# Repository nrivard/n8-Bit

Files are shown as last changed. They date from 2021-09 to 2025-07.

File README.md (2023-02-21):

# n8 Bit Microcomputer

The n8 Bit Microcomputer is a homebrew breadboard computer built around a WDC65C02 8-bit CPU.
If you are looking for the software that runs on this computer, check out [LmaOS](https://github.com/nrivard/lmaos).

## History

The n8 Bit was originally a breadboard computer based on the [Ben Eater series of 6502 videos](https://www.youtube.com/playlist?list=PLowKtXNTBypFbtuVMUVXNR0z1mu7dp7eH) but with some added capabilities including ACIA support, GAL-based address decoding logic, and a power chip for more reliable reset and power-on.
Since then, PCBs have been printed and development around the computer is based on these.

nate bit microcomputer on a breadboard

## Physical Design

Large PCBs are expensive and I am not a rich person.
For this reason, the main goal of the physical design of this computer and the expansion cards is to fit on the $5 boards at the cheap PCB houses.
This gives a maximum area of 100mm x 100mm, which this board attempts to utilize to the utmost.

## Main Board

The v2 main board is built around a WDC65C02 CPU operating at 3.6864Mhz and is meant to be as minimally viable as possible. It consists of:

* 3 memory sockets (AT28C256/CY62256 footprint) for a configurable mix of RAM and/or ROM
* SC28L92 DUART for serial communication and built-in timer(s)
* CH340 USB-to-serial chip
* Micro USB port for power (D+/D- are connected to the CH340)
* GAL22V10 for flexible address decoding
* Crystal oscillator can for stable clock generation
* 74HC21 for multi-device IRQ and handling (supports older open-collector devices with jumpers on built-in pull-up resistors)
* DS1813 for reset and power-on circuitry
* 3 n8 Bus ports for I/O

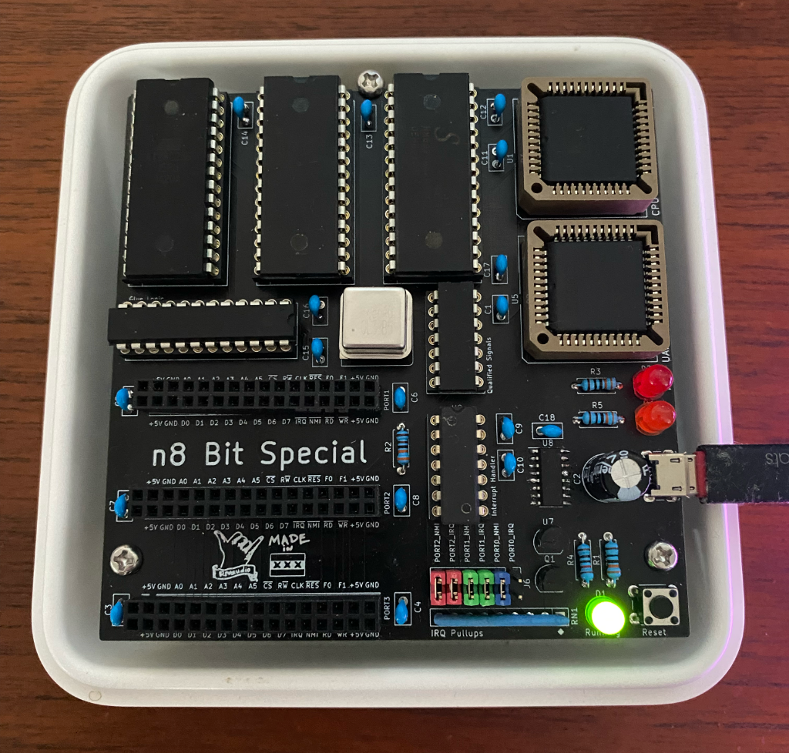
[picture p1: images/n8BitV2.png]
nate bit microcomputer, version 1


### Changes from v1

* Moved from 4 n8 Bus ports down to 3. This was mainly for space reasons and one of the previous ports was always dedicated to serial communication and a VIA for a timer. By moving both of these onto the board, we can give some more breathing room to 3 expansion ports instead
* Moved to half-size oscillator can and increased speed to 3.6864 MHz. The DUART runs at this frequency so I made this the main clock as well.
* Moved to PLCC-44 packaging for CPU and DUART. This not only looks cooler but it has a smaller footprint and allowed me more room to lay out additional components.
* Added transistor stage to the "running" light so it shows when it's actually running, not just when there is power to the board. Pressing and holding RESET will drive this LED off while RESET is low.
* Added qualified (ANDed with CLK) read and write signals to the board and to the n8 Bus ports, replacing D+/D-.
* Ran CLK into the GAL in case I want to use its signal to qualify future signals.
* Moved from 2 layer to 4 layer board. So many signals! Also, this is auto-routed, I don't care, I'm not a purist in this (one) sense

nate bit microcomputer, version 1

## Address space

By default, the n8 Bit is intended to have the following memory hardware:

* 1 Atmel AT28C256 in the ROM1 socket
* 2 Cypress CY62256NL in the RAM1 and RAM2 sockets

### Default Memory Layout

If you are using the default hardware and the included GAL code, it has the following memory layout:

| Device | Address Range |
|---|---|
| Zero Page | `$0000...$00FF` |
| Stack | `$0100...$01FF` |
| RAM | `$0200...$BEFF` |
| Port 0 | `$BF00...$BF3F` |
| Port 1 | `$BF40...$BF7F` |
| Port 2 | `$BF80...$BFBF` |
| DUART | `$BFC0...$BFFF` |
| ROM | `$C000...$FFFF` |

This configuration has 16K of ROM, 48k (less one page) of RAM, and 1 page of memory (`$BF00...$BFFF`) dedicated to 3 I/O ports and the DUART, each of which has 64 addressable memory locations.

### Customizing the Address Space

Because address decoding is entirely GAL based, you have a lot of room to customize the address space.
The GAL itself has physical connections to each port and to each memory socket for CS signals. How you utilize these (or even _if_ you utilize them) is entirely up to you.
If you wanted a simpler computer (like the Ben Eater computer) you may opt to leave one memory socket open and only use a single RAM and a single ROM chip.
If you go this route, you will have to update your own GAL code to match your hardware configuration.

## n8 Bus

The biggest advancement with the n8 Bit when it moved from breadboards to custom PCBs is the introduction of the n8 Bus spec.

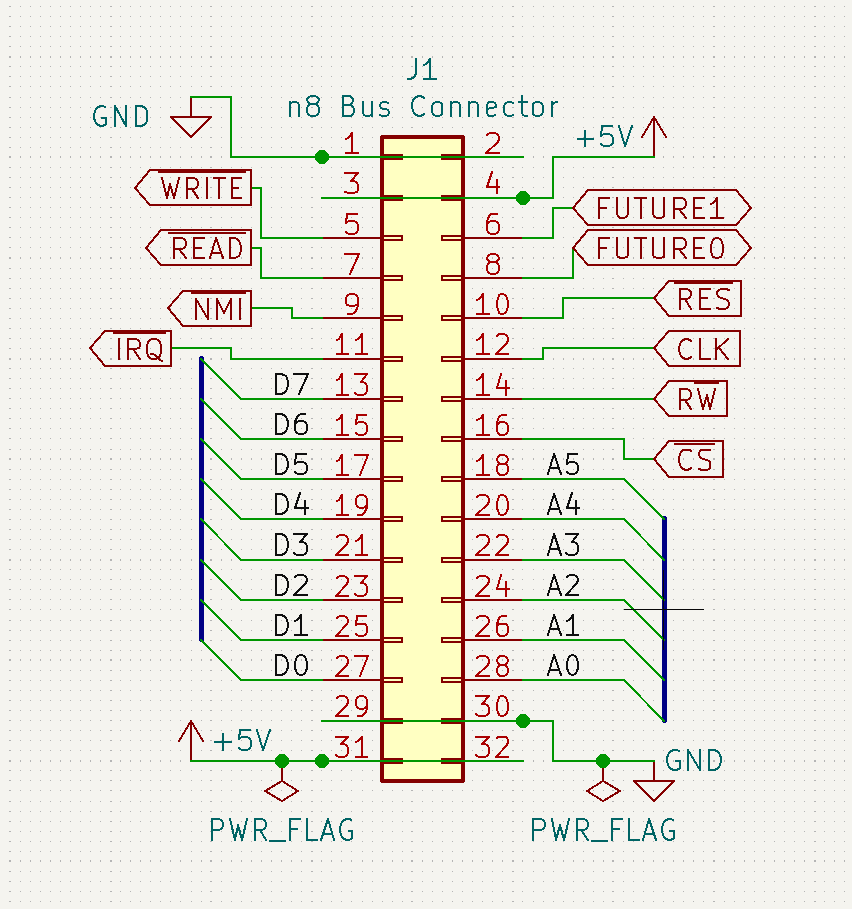
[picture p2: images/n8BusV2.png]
nate bus schematic, version 1


The spec mandates that the following signals will be available on a standard 2x16 board-to-board female header:

**Bidirectional signals:**

* all 8 bits of the data bus

**Read-only signals:**

* bottom 6 bits of the address bus
* per-port dedicated <SPAN STYLE="text-decoration:overline">CS</SPAN> signal
* CPU's R/<SPAN STYLE="text-decoration:overline">W</SPAN> signal
* <SPAN STYLE="text-decoration:overline">READ</SPAN> signal qualified with high part of the CLK
* <SPAN STYLE="text-decoration:overline">WRITE</SPAN> signal qualified with high part of the CLK
* CLK
* <SPAN STYLE="text-decoration:overline">RESET</SPAN>

**Write-only signals:**

* per-port <SPAN STYLE="text-decoration:overline">NMI</SPAN>
* per-port <SPAN STYLE="text-decoration:overline">IRQ</SPAN>

**Expansion signals:**

The n8 Bus spec includes 2 lines (`FUTURE0` and `FUTURE1`) that don't currently have a purpose.
These are hooked up to 2 I/O pins of the GAL and are intended for you to customize them.
For example, if you have a VDP that outputs a colorburst clock that you want to use to drive a sound adapter, you can route that signal through one of these pins.

**Power Rails:**

The n8 Bus spec provides power rails (+5V and ground) on both the top and bottom of the header for shorter, more convenient power routing on your expansions cards.

## I/O Expansion Cards

The main board for this computer is intentionally minimal.
This means that all of your I/O functionality beyond a DUART (VIA, display, sound, etc.) has to come in the form of an expansion card that sits in a n8 Bus port.

### Reference Cards

Two highly utilized devices that many hobbyists want to include on a homebrew computer are a UART (this is unnecessary now on the v2 board but is kept for reference purposes) and a GPIO device.
In this repo, 2 such reference designs are included:

* a UART card based on the Rockwell 65C51, called Kids Serial
* a GPIO (and other functions) card based on the WDC65C22S, called Viaduct

### Custom Cards

If you want to create your own cards, it's best to copy one of the existing reference designs first.
This is because they will already have:

* the n8 Bus port with proper pin directionality _for the card_ in the schematic
* a standardized PCB footprint
* some device footprints (like the 2x16 right-angle male pin header) set

This will ensure you have consistent and correct card designs from the start.

Kids Serial, a UART card, version 1

## Interrupts

<SPAN STYLE="text-decoration:overline">NMI</SPAN> and <SPAN STYLE="text-decoration:overline">IRQ</SPAN> are supported for all 3 n8 Bus ports.
This board uses a WDC65C02 which uses a totem-pole design (the NMOS 6502 used an open-drain design) and so the board also includes optional jumpers for pull-up resistors. In general:

* if your device is open-drain (older 6551s) or your device does not support interrupts at all, you will need to **_add_** jumpers across the interrupt lines for that port
* if your device is totem-pole (WDC65C22S), you will want to **_remove_** the jumpers as the pull-up resistor will slow down signal change

See [this article from Garth Wilson](http://wilsonminesco.com/6502primer/IRQconx.html) for more information.

## Known Bugs

There are no known hardware bugs with the v2 board.
If you find one (or more) please raise an issue.

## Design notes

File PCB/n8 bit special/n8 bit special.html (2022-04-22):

# /Users/nrivard/Code/github/n8-Bit/PCB/n8 bit special/n8 bit special.sch

2022 February 22, Tuesday 14:28:18

Eeschema (5.1.12-1-10_14)

Component Count:48

Ref | Qnty | Value | Part | Footprint | Description | Vendor
C1, C3, C4, C5, C6, C7, C8, C11, C12, C13, C14, C15, C16 | 13 | 100nf | Device:C_Small | Capacitor_THT:C_Disc_D5.0mm_W2.5mm_P2.50mm | Unpolarized capacitor, small symbol
C2 | 1 | 470uF | Device:CP | Capacitor_THT:CP_Radial_D8.0mm_P3.80mm | Polarized capacitor
C9, C17, C18 | 3 | 100nF | Device:C_Small | Capacitor_THT:C_Disc_D5.0mm_W2.5mm_P2.50mm | Unpolarized capacitor, small symbol
C19, C20 | 2 | 47pF | Device:C_Small | Capacitor_THT:C_Disc_D5.0mm_W2.5mm_P2.50mm | Unpolarized capacitor, small symbol
D1 | 1 | LED_ALT | Device:LED_ALT | LED_THT:LED_D3.0mm | Light emitting diode, filled shape
D2 | 1 | TX | Device:LED | LED_THT:LED_D3.0mm | Light emitting diode
D3 | 1 | RX | Device:LED | LED_THT:LED_D3.0mm | Light emitting diode
J1 | 1 | USB_B_Micro | Connector:USB_B_Micro | Connector_USB:USB_Micro-B_Amphenol_10118194_Horizontal | USB Micro Type B connector
J2 | 1 | PORT0 | Connector_Generic:Conn_02x16_Odd_Even | Connector_PinSocket_2.54mm:PinSocket_2x16_P2.54mm_Vertical | Generic connector, double row, 02x16, odd/even pin numbering scheme (row 1 odd numbers, row 2 even numbers), script generated (kicad-library-utils/schlib/autogen/connector/)
J3 | 1 | PORT2 | Connector_Generic:Conn_02x16_Odd_Even | Connector_PinSocket_2.54mm:PinSocket_2x16_P2.54mm_Vertical | Generic connector, double row, 02x16, odd/even pin numbering scheme (row 1 odd numbers, row 2 even numbers), script generated (kicad-library-utils/schlib/autogen/connector/)
J4 | 1 | PORT1 | Connector_Generic:Conn_02x16_Odd_Even | Connector_PinSocket_2.54mm:PinSocket_2x16_P2.54mm_Vertical | Generic connector, double row, 02x16, odd/even pin numbering scheme (row 1 odd numbers, row 2 even numbers), script generated (kicad-library-utils/schlib/autogen/connector/)
J6 | 1 | Conn_02x08_Odd_Even | Connector_Generic:Conn_02x06_Odd_Even | Connector_PinHeader_2.54mm:PinHeader_2x06_P2.54mm_Vertical | Generic connector, double row, 02x06, odd/even pin numbering scheme (row 1 odd numbers, row 2 even numbers), script generated (kicad-library-utils/schlib/autogen/connector/)
Q1 | 1 | 2N3904 | Transistor_BJT:2N3904 | Package_TO_SOT_THT:TO-92 | 0.2A Ic, 40V Vce, Small Signal NPN Transistor, TO-92
R1, R5, R6 | 3 | 220 | Device:R | Resistor_THT:R_Axial_DIN0207_L6.3mm_D2.5mm_P7.62mm_Horizontal | Resistor
R2 | 1 | 3K3 | Device:R | Resistor_THT:R_Axial_DIN0207_L6.3mm_D2.5mm_P7.62mm_Horizontal | Resistor
R4 | 1 | 10K | Device:R | Resistor_THT:R_Axial_DIN0207_L6.3mm_D2.5mm_P7.62mm_Horizontal | Resistor
R7, R8 | 2 | 27 | Device:R | Resistor_THT:R_Axial_DIN0207_L6.3mm_D2.5mm_P7.62mm_Horizontal | Resistor
RN1 | 1 | 3K3 | Device:R_Network08 | Resistor_THT:R_Array_SIP9 | 8 resistor network, star topology, bussed resistors, small symbol
SW1 | 1 | SW_Push_Dual | Switch:SW_Push_Dual_x2 | Button_Switch_THT:SW_PUSH_6mm | Push button switch, generic, separate symbols, four pins
U1 | 1 | W65C02SxP | 65xx:W65C02SxPL | Package_LCC:PLCC-44_THT-Socket | W65C02S 8-bit CMOS General Purpose Microprocessor, PLCC-44
U2, U3 | 2 | CY62256-70PC | Memory_RAM:CY62256-70PC | Package_DIP:DIP-28_W15.24mm_Socket | 256K (32K x 8) Static RAM, 70ns, DIP-28
U4 | 1 | 28C256 | Memory_EEPROM:28C256 | Package_DIP:DIP-28_W15.24mm_Socket | Paged Parallel EEPROM 256Kb (32K x 8), DIP-28/SOIC-28
U5 | 1 | 74LS21 | 74xx:74LS21 | Package_DIP:DIP-14_W7.62mm_Socket | Dual 4-input AND
U6 | 1 | 22V10C | 6502:22V10C | Package_DIP:DIP-24_W7.62mm_Socket
U7 | 1 | DS1813 | 6502:DS1813 | Package_TO_SOT_THT:TO-92
U8 | 1 | SC28L92_PLC44 | 65xx:SC28L92_PLC44 | Package_LCC:PLCC-44_THT-Socket | DUART in a PLC44 through-hole package
U9 | 1 | FT230XS | Interface_USB:FT230XS | Package_SO:SSOP-16_3.9x4.9mm_P0.635mm | Full Speed USB to Basic UART, SSOP-16
U10 | 1 | 74HC00 | 74xx:74HC00 | Package_DIP:DIP-14_W7.62mm_Socket | quad 2-input NAND gate
X1 | 1 | 3.6864Mhz | Oscillator:CXO_DIP8 | Oscillator:Oscillator_DIP-8 | Crystal Clock Oscillator, DIP8-style metal package

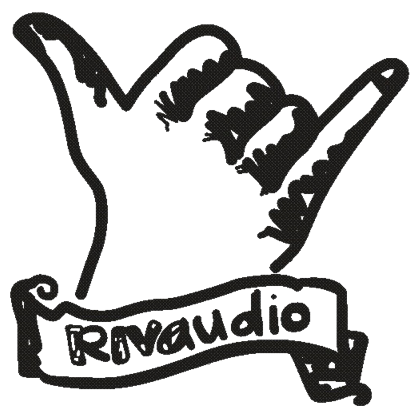
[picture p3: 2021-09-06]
PCB/n8 bit special/bitmaps/Shaka.png

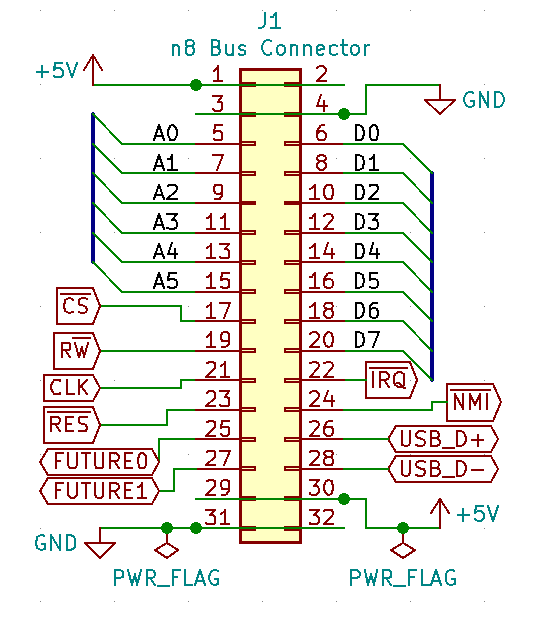
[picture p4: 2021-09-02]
images/n8BusV1.png

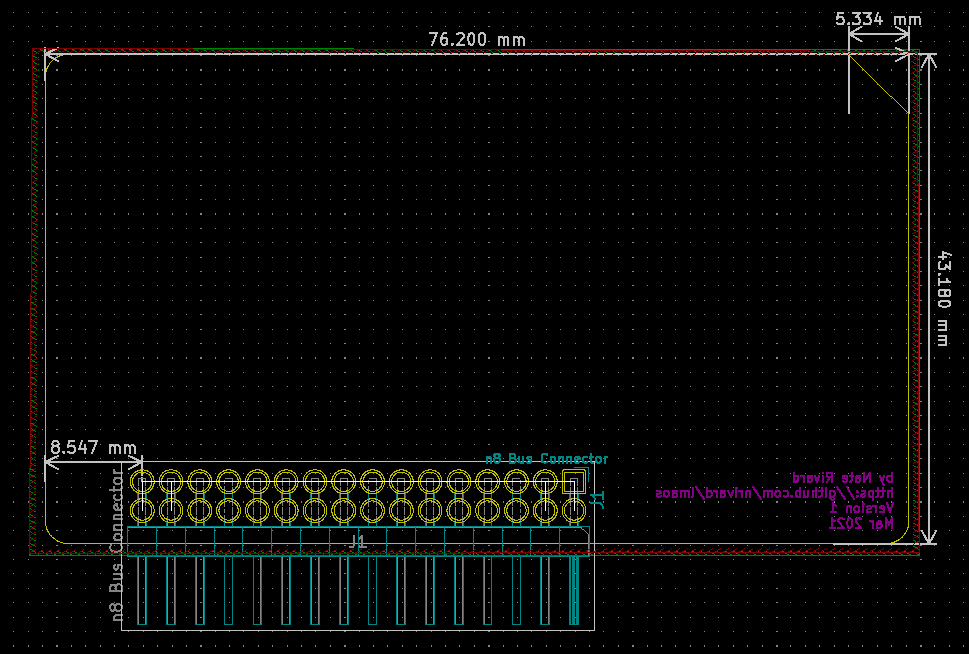
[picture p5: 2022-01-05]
PCB/n8 bus/meta/brd.png

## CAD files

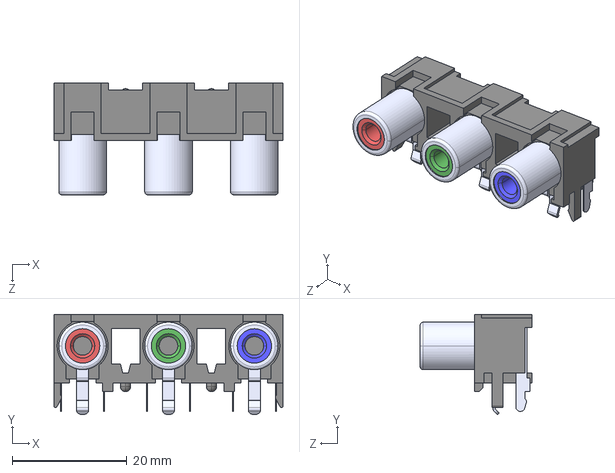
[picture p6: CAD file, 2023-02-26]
PCB/pixel juice/PJRAN3X1U03X/PJRAN3X1U03X.step
40.0 x 17.5 x 19.5 mm

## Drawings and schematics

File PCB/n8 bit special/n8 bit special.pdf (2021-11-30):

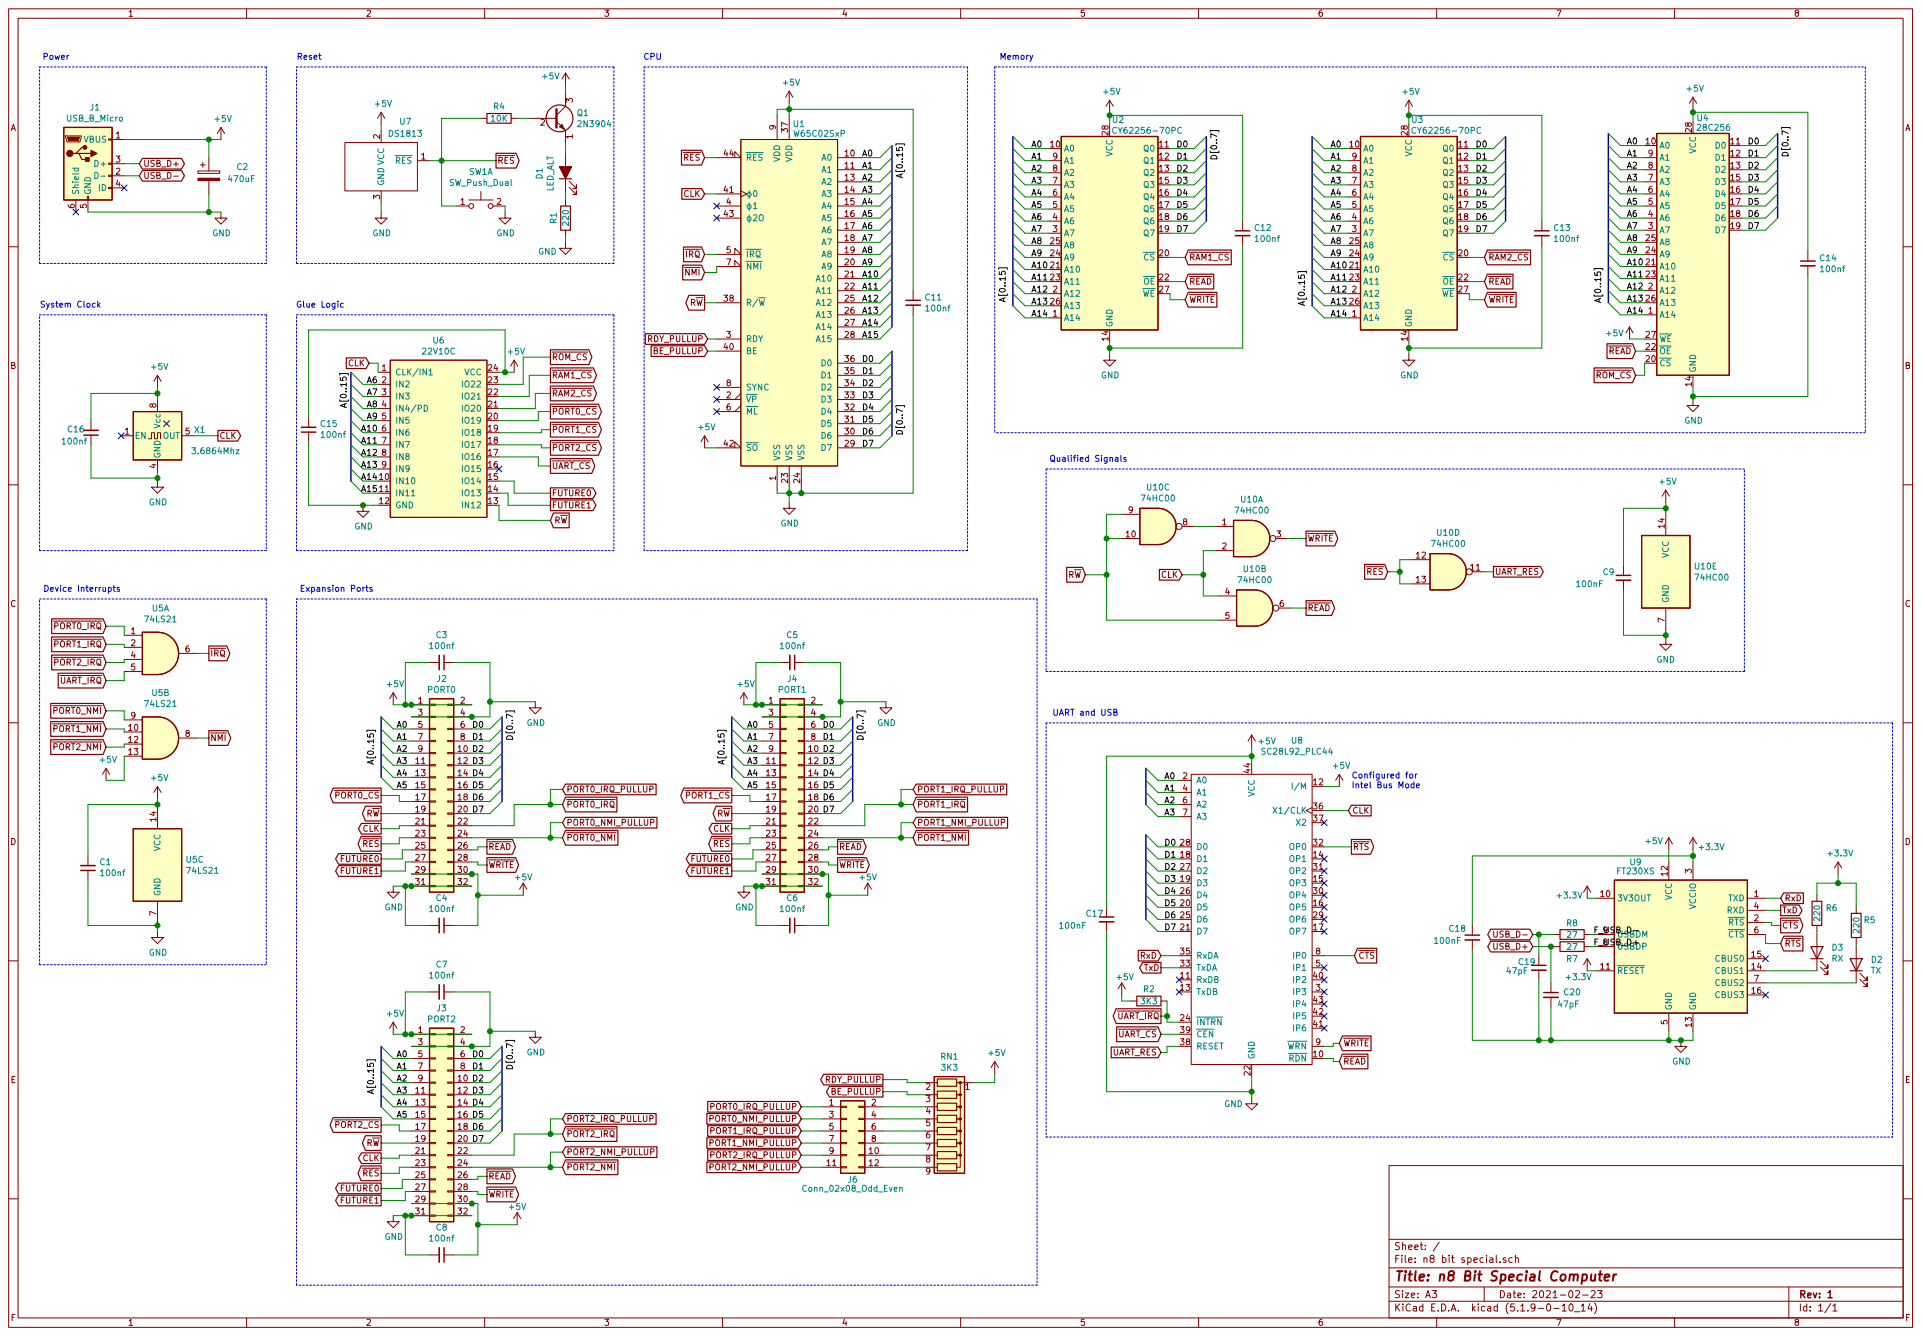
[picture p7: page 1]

3 U7 DS1813 GND 14 VCC 28 A14 1 A0 10 Q0 11 Q1 12 Q2 13 Q3 15 Q4 16 Q5 17 Q6 18 Q7 19 A12 2 CS 20 A10 21 OE 22 A11 23 A9 24 A8 25 A13 26 WE 27 A7 3 A6 4 A5 5 A4 6 A3 7 A2 8 A1 9 U2CY62256-70PC

1 A0 10 A1 11 A2 13 A3 14 A4 15 A5 16 A6 17 A7 18 A8 19 VP 2 A9 20 A10 21 A11 22 VSS 23 VSS 24 A12 25 A13 26 A14 27 A15 28 D7 29 RDY 3 D6 30 D5 31 D4 32 D3 33 D2 34 D1 35 D0 36 VDD 37 R/W 38

RTS CTS RTS READ

File: n8 bit special.sch Sheet: /
Id: 1/1 Title: n8 Bit Special Computer

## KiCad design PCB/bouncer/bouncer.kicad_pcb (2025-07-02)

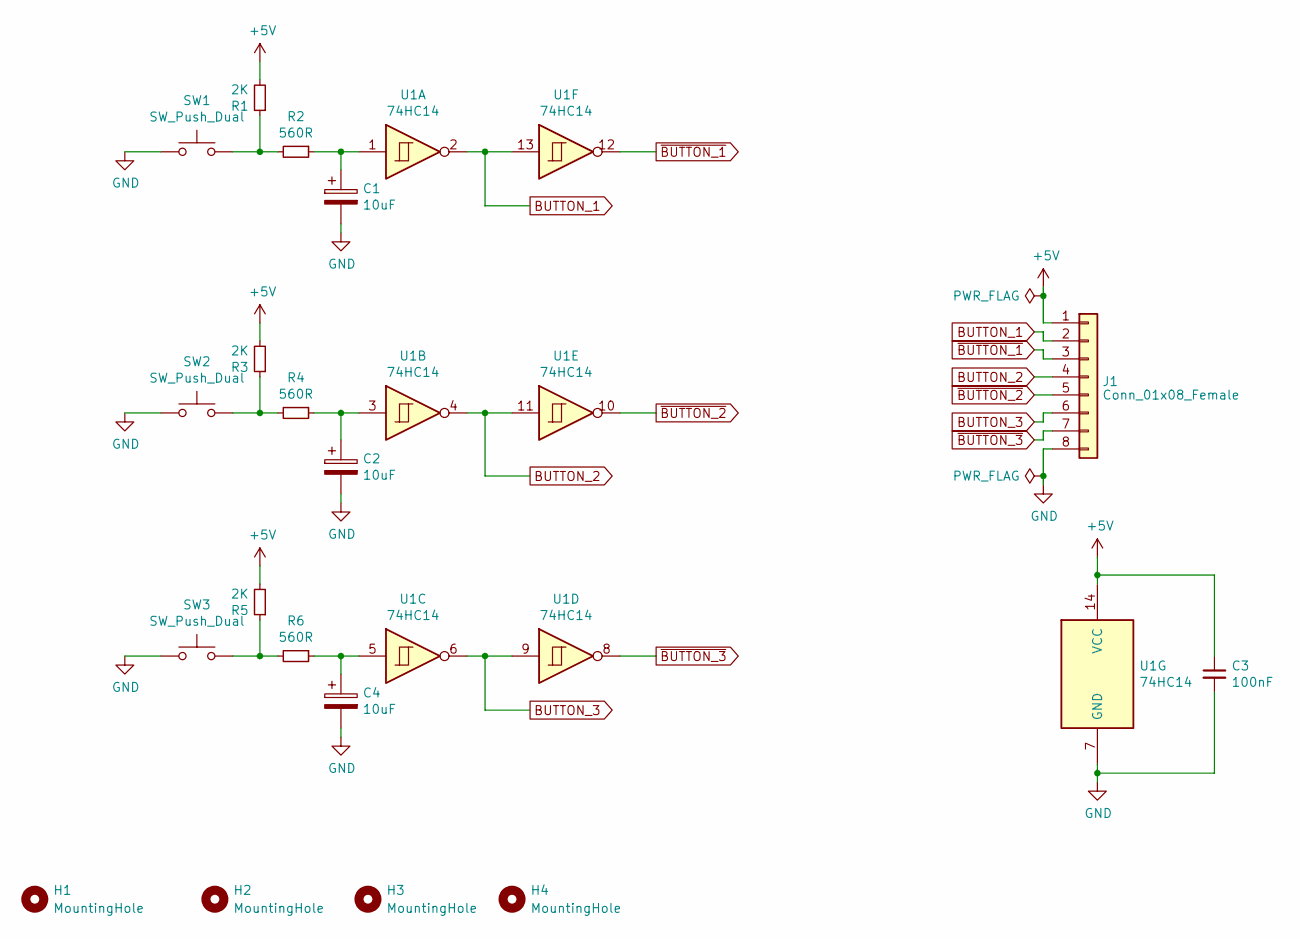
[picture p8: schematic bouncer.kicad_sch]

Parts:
C1, C2, C4: 10uF; CP_Radial_D4.0mm_P2.00mm
C3: 100nF; C_Disc_D5.0mm_W2.5mm_P2.50mm
H1, H2, H3, H4: MountingHole; MountingHole_3.2mm_M3_DIN965_Pad
J1: Conn_01x08_Female; PinSocket_1x08_P2.54mm_Vertical
R1, R3, R5: 2K; R_Axial_DIN0207_L6.3mm_D2.5mm_P7.62mm_Horizontal
R2, R4, R6: 560R; R_Axial_DIN0207_L6.3mm_D2.5mm_P7.62mm_Horizontal
SW1, SW2, SW3: SW_Push_Dual; SW_PUSH-12mm
U1: 74HC14; DIP-14_W7.62mm

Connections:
+5V: C3.1, J1.1, R1.2, R3.2, R5.2, U1.14 (VCC)
BUTTON_1: J1.2, U1.2, U1.13
BUTTON_2: J1.4, U1.4, U1.11
BUTTON_3: J1.6, U1.6, U1.9
GND: C1.2, C2.2, C3.2, C4.2, J1.8, SW1.1, SW2.1, SW3.1, U1.7 (GND)
unnamed: C1.1, R2.1, U1.1
unnamed: C2.1, R4.1, U1.3
unnamed: C4.1, R6.1, U1.5
unnamed: R1.1, R2.2, SW1.2
unnamed: R3.1, R4.2, SW2.2
unnamed: R5.1, R6.2, SW3.2
~BUTTON_1: J1.3, U1.12
~BUTTON_2: J1.5, U1.10
~BUTTON_3: J1.7, U1.8

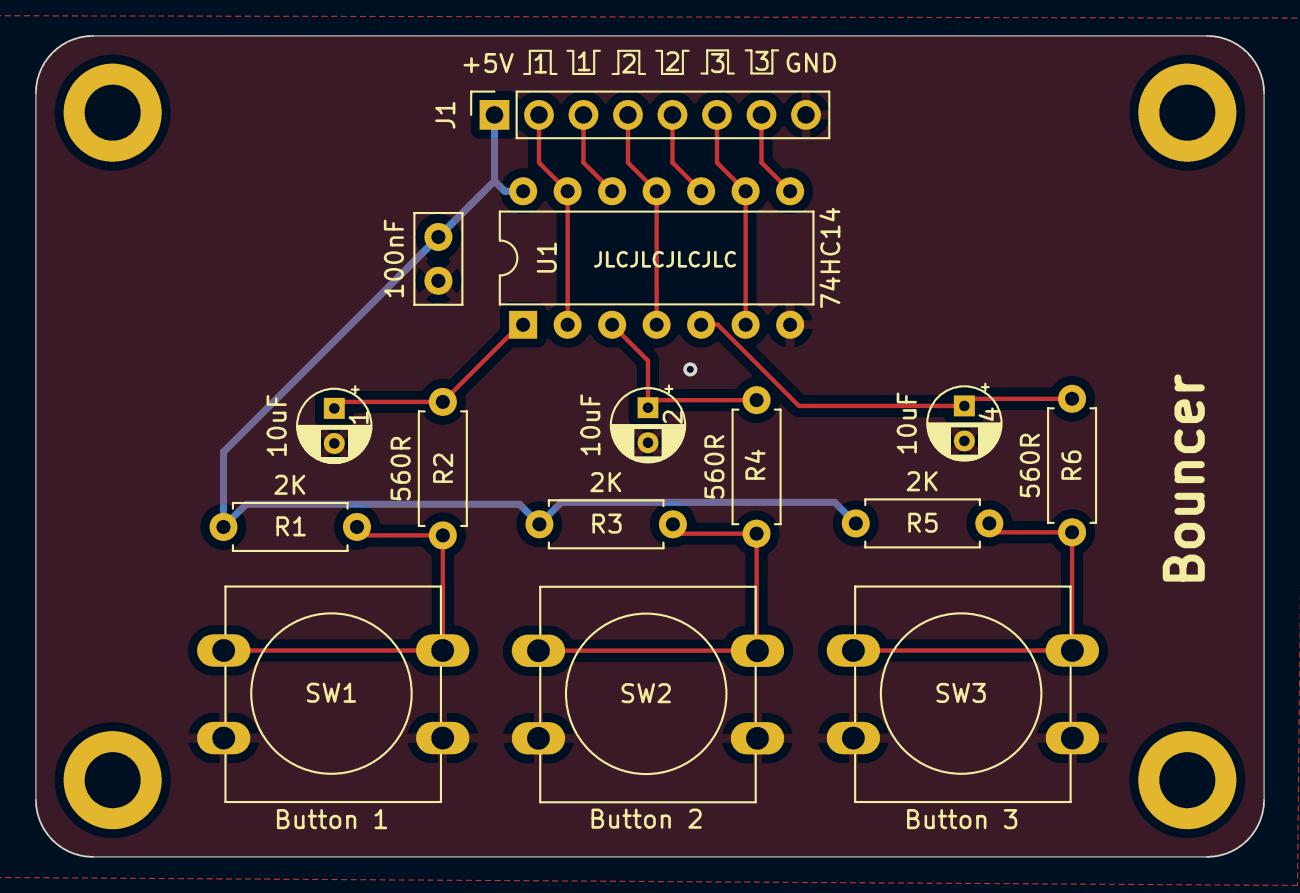
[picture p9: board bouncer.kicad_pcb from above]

Board: 2 copper layers, 70.1 x 46.9 mm, 19 parts (0 on the bottom side), 14 nets.

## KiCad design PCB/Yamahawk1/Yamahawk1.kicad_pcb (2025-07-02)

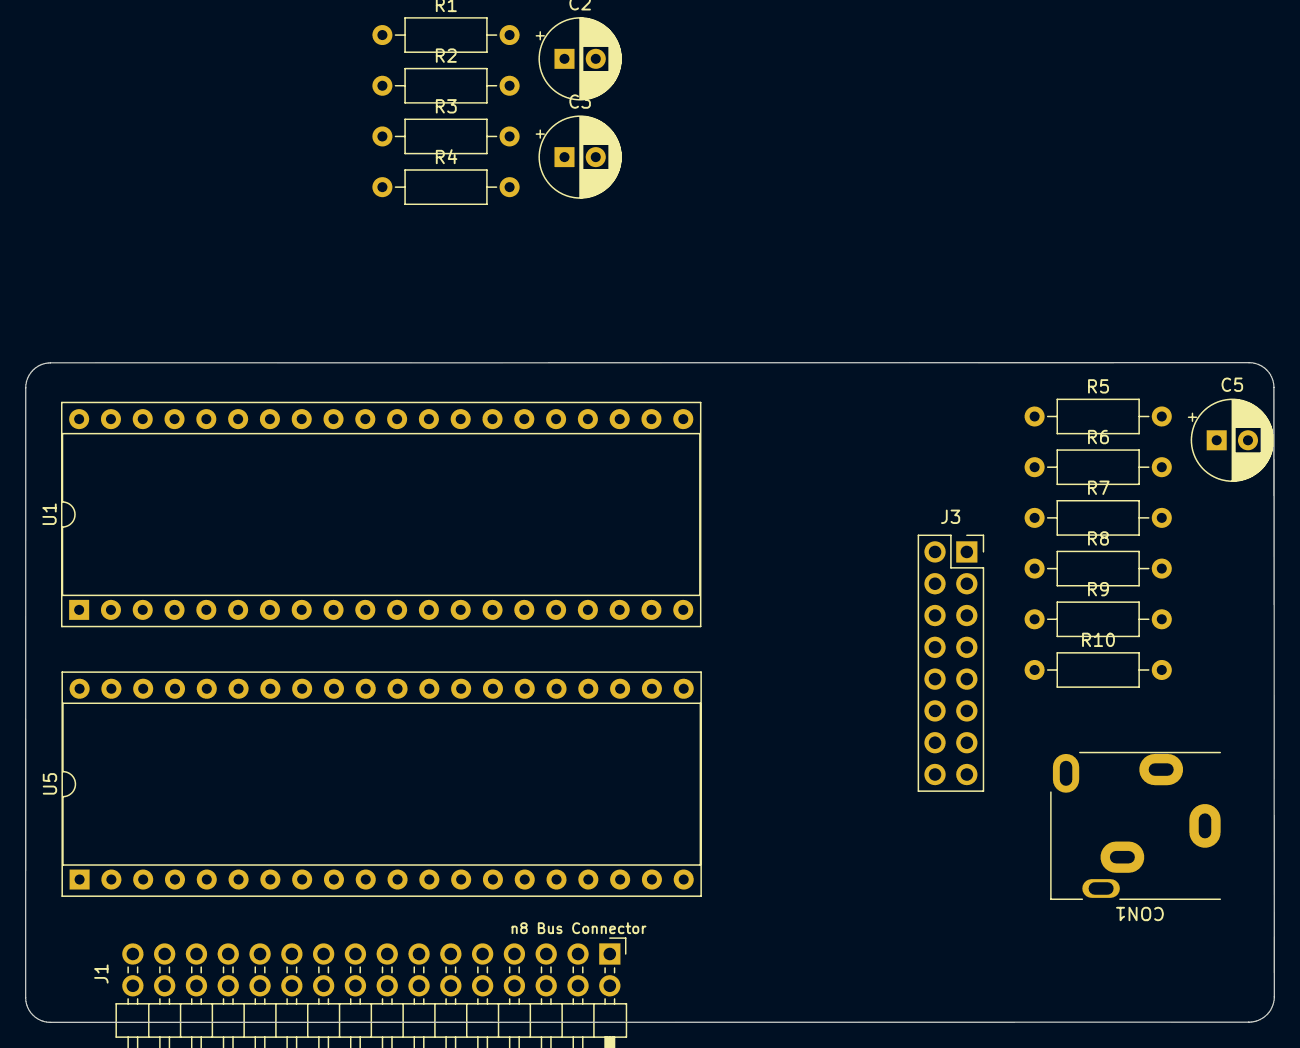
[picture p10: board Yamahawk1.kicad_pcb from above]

Board: 2 copper layers, 99.7 x 52.7 mm, 18 parts (0 on the bottom side), 39 nets, no tracks yet.

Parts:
C2, C3: 4.7uF; CP_Radial_D6.3mm_P2.50mm
C5: 220uf; CP_Radial_D6.3mm_P2.50mm
CON1: SJ1-3523N; Jack_3.5mm_CUI_SJ1-3515N_Horizontal
J1: n8 Bus Connector; PinHeader_2x16_P2.54mm_Horizontal
J3: SPKR_{OUT}; PinSocket_2x08_P2.54mm_Vertical
R1, R2, R3: 3K; R_Axial_DIN0207_L6.3mm_D2.5mm_P10.16mm_Horizontal
R4, R5: 1K; R_Axial_DIN0207_L6.3mm_D2.5mm_P10.16mm_Horizontal
R6, R7: 1K6; R_Axial_DIN0207_L6.3mm_D2.5mm_P10.16mm_Horizontal
R8, R9: 8K2; R_Axial_DIN0207_L6.3mm_D2.5mm_P10.16mm_Horizontal
R10: 10R; R_Axial_DIN0207_L6.3mm_D2.5mm_P10.16mm_Horizontal
U1: YM2149; DIP-40_W15.24mm_Socket
U5: 65C22S; DIP-40_W15.24mm_Socket

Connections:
+5V: J1.3, J1.4, J1.31, J1.32, U1.25 (A8), U1.28 (BC2), U1.40 (VCC), U5.20 (VDD), U5.24 (CS1)
/A0: J1.28, U5.38 (RS0)
/A1: J1.26, U5.37 (RS1)
/A2: J1.24, U5.36 (RS2)
/A3: J1.22, U5.35 (RS3)
/D0: J1.27, U5.33 (D0)
/D1: J1.25, U5.32 (D1)
/D2: J1.23, U5.31 (D2)
/D3: J1.21, U5.30 (D3)
/D4: J1.19, U5.29 (D4)
/D5: J1.17, U5.28 (D5)
/D6: J1.15, U5.27 (D6)
/D7: J1.13, U5.26 (D7)
/LEFT: C2.2, CON1.T
/PA0: U1.37 (DA0), U5.2 (PA0)
/PA1: U1.36 (DA1), U5.3 (PA1)
/PA2: U1.35 (DA2), U5.4 (PA2)
/PA3: U1.34 (DA3), U5.5 (PA3)
/PA4: U1.33 (DA4), U5.6 (PA4)
/PA5: U1.32 (DA5), U5.7 (PA5)
/PA6: U1.31 (DA6), U5.8 (PA6)
/PA7: U1.30 (DA7), U5.9 (PA7)
/RIGHT: C3.2, CON1.R
AMP_{LEFT}: CON1.TN, R9.1
AMP_{RIGHT}: CON1.RN, R8.1
BC1: U1.29 (BC1), U5.39 (CA2)
CH_A: R2.1, R5.2, U1.4 (CH_A)
CH_B: R3.1, R4.2, U1.3 (CH_B)
CH_C: R1.1, R6.2, R7.2, U1.38 (CH_C)
CLK: J1.12, U5.25 (PHI2)
GND: CON1.S, J1.1, J1.2, J1.29, J1.30, J3.2, R1.2, R2.2, R3.2, R10.2, U1.1 (GND), U1.24 (~A9), U1.26 (~SEL), U5.1 (VSS)
unnamed: C2.1, R4.1, R7.1
unnamed: C3.1, R5.1, R6.1
unnamed: C5.2, J3.1
unnamed: R8.2, R9.2
R~W: J1.14, U5.22 (R~W)
~CS: J1.16, U5.23 (~CS2)
~IRQ: J1.11, U5.21 (~IRQ)
~RES: J1.10, U5.34 (~RES)

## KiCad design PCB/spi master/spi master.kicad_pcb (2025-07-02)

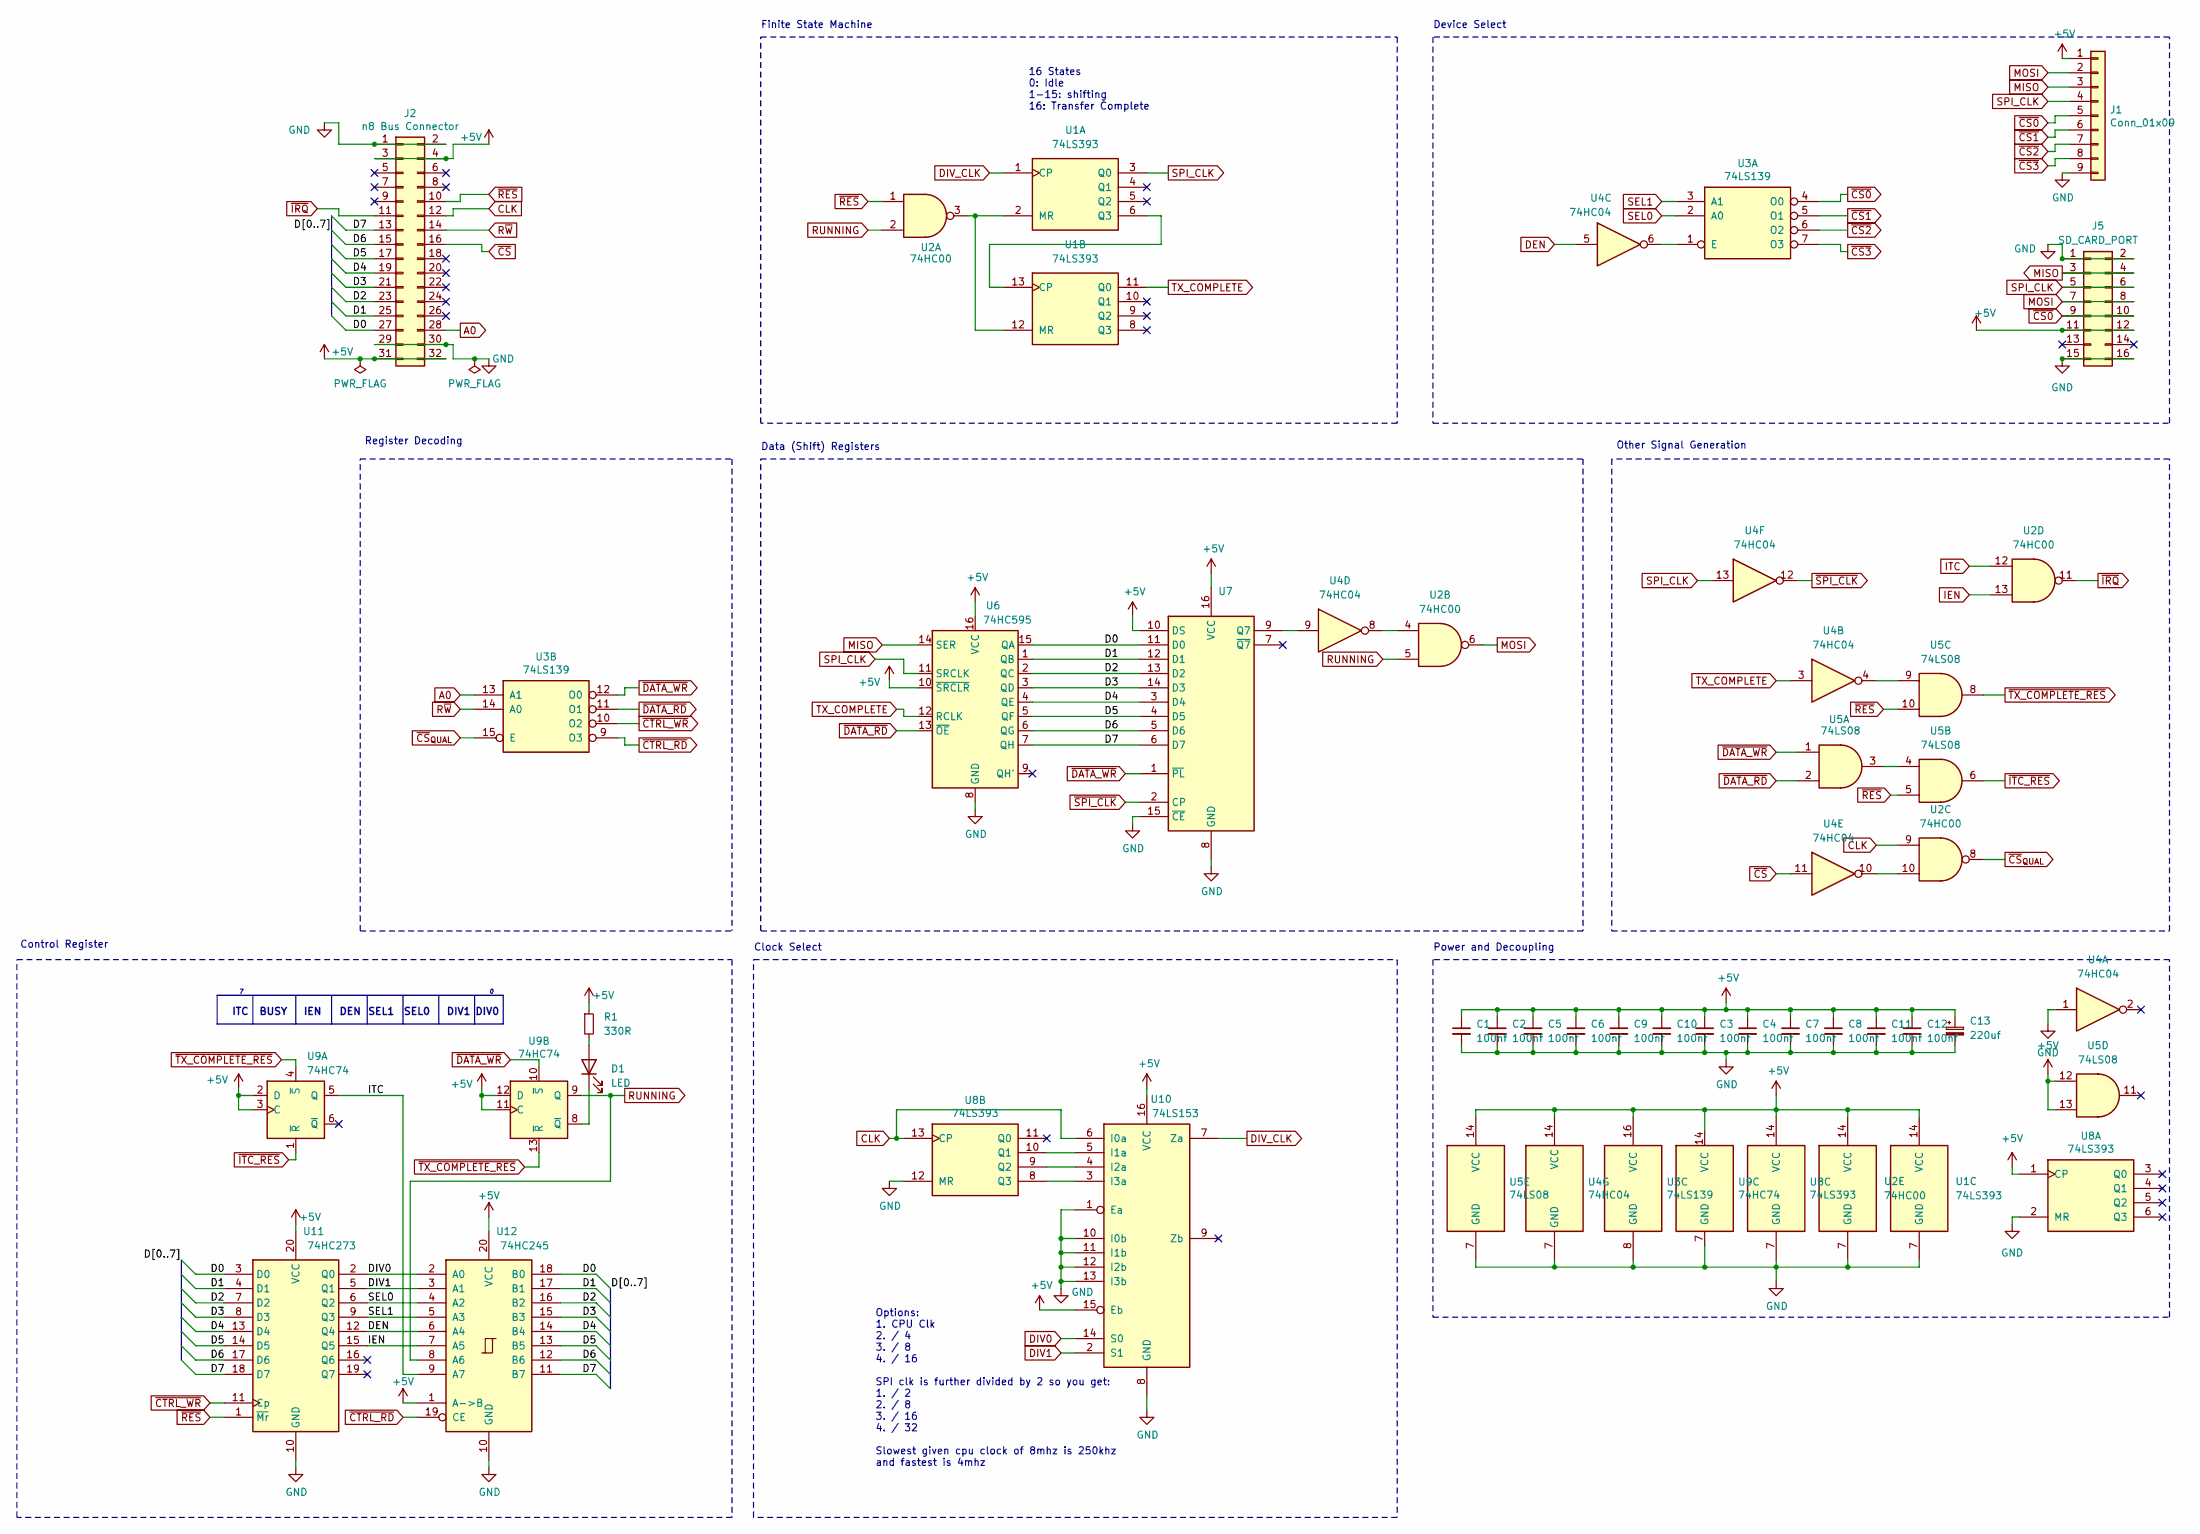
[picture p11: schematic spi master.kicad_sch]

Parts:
C1, C2, C3, C4, C5, C6, C7, C8, C9, C10, C11, C12: 100nf; C_Disc_D5.0mm_W2.5mm_P2.50mm
C13: 220uf; CP_Radial_D6.3mm_P2.50mm
D1: LED; LED_0805_2012Metric_Pad1.15x1.40mm_HandSolder
J1: Conn_01x09; PinSocket_1x09_P2.54mm_Horizontal
J2: n8 Bus Connector; PinHeader_2x16_P2.54mm_Horizontal
J5: SD_CARD_PORT; PinSocket_2x08_P2.54mm_Vertical
R1: 330R; R_0805_2012Metric_Pad1.20x1.40mm_HandSolder
U1, U8: 74LS393; DIP-14_W7.62mm_Socket
U2: 74HC00; DIP-14_W7.62mm_Socket
U3: 74LS139; DIP-16_W7.62mm_Socket
U4: 74HC04; DIP-14_W7.62mm_Socket
U5: 74LS08; DIP-14_W7.62mm_Socket
U6: 74HC595; DIP-16_W7.62mm_Socket
U7: 74HC165; DIP-16_W7.62mm_Socket
U9: 74HC74; DIP-14_W7.62mm_Socket
U10: 74LS153; DIP-16_W7.62mm_Socket
U11: 74HC273; DIP-20_W7.62mm_Socket
U12: 74HC245; DIP-20_W7.62mm_Socket

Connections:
+5V: C1.1, C2.1, C3.1, C4.1, C5.1, C6.1, C7.1, C8.1, C9.1, C10.1, C11.1, C12.1, C13.1, J1.1, J2.3, J2.4, J2.31, J2.32, J5.11, J5.12, R1.1, U1.14 (VCC), U2.14 (VCC), U3.16 (VCC), U4.14 (VCC), U5.12, U5.13, U5.14 (VCC), U6.10 (~SRCLR), U6.16 (VCC), U7.10 (DS), U7.16 (VCC), U8.1 (CP), U8.14 (VCC), U9.2 (D), U9.3 (C), U9.11 (C), U9.12 (D), U9.14 (VCC), U10.15 (Eb), U10.16 (VCC), U11.20 (VCC), U12.1 (A->B), U12.20 (VCC)
/D0: J2.27, U6.15 (QA), U7.11 (D0), U11.3 (D0), U12.18 (B0)
/D1: J2.25, U6.1 (QB), U7.12 (D1), U11.4 (D1), U12.17 (B1)
/D2: J2.23, U6.2 (QC), U7.13 (D2), U11.7 (D2), U12.16 (B2)
/D3: J2.21, U6.3 (QD), U7.14 (D3), U11.8 (D3), U12.15 (B3)
/D4: J2.19, U6.4 (QE), U7.3 (D4), U11.13 (D4), U12.14 (B4)
/D5: J2.17, U6.5 (QF), U7.4 (D5), U11.14 (D5), U12.13 (B5)
/D6: J2.15, U6.6 (QG), U7.5 (D6), U11.17 (D6), U12.12 (B6)
/D7: J2.13, U6.7 (QH), U7.6 (D7), U11.18 (D7), U12.11 (B7)
A0: J2.28, U3.13 (A1)
CLK: J2.12, U2.9, U8.13 (CP), U10.6 (I0a)
DEN: U4.5, U11.12 (Q4), U12.6 (A4)
DIV0: U10.14 (S0), U11.2 (Q0), U12.2 (A0)
DIV1: U10.2 (S1), U11.5 (Q1), U12.3 (A1)
DIV_CLK: U1.1 (CP), U10.7 (Za)
GND: C1.2, C2.2, C3.2, C4.2, C5.2, C6.2, C7.2, C8.2, C9.2, C10.2, C11.2, C12.2, C13.2, J1.9, J2.1, J2.2, J2.29, J2.30, J5.1, J5.2, J5.15, J5.16, U1.7 (GND), U2.7 (GND), U3.8 (GND), U4.1, U4.7 (GND), U5.7 (GND), U6.8 (GND), U7.8 (GND), U7.15 (~CE), U8.2 (MR), U8.7 (GND), U8.12 (MR), U9.7 (GND), U10.1 (Ea), U10.8 (GND), U10.10 (I0b), U10.11 (I1b), U10.12 (I2b), U10.13 (I3b), U11.10 (GND), U12.10 (GND)
IEN: U2.13, U11.15 (Q5), U12.7 (A5)
ITC: U2.12, U9.5 (Q), U12.9 (A7)
MISO: J1.3, J5.3, J5.4, U6.14 (SER)
MOSI: J1.2, J5.7, J5.8, U2.6
unnamed: D1.2 (A), R1.2
unnamed: D1.1 (K), U9.8 (~Q)
unnamed: U1.2 (MR), U1.12 (MR), U2.3
unnamed: U1.6 (Q3), U1.13 (CP)
unnamed: U2.4, U4.8
unnamed: U2.10, U4.10
unnamed: U3.1 (E), U4.6
unnamed: U4.4, U5.9
unnamed: U5.3, U5.4
unnamed: U4.9, U7.9 (Q7)
unnamed: U8.10 (Q1), U10.5 (I1a)
unnamed: U8.9 (Q2), U10.4 (I2a)
unnamed: U8.8 (Q3), U10.3 (I3a)
RUNNING: U2.2, U2.5, U9.9 (Q), U12.8 (A6)
R~W: J2.14, U3.14 (A0)
SEL0: U3.2 (A0), U11.6 (Q2), U12.4 (A2)
SEL1: U3.3 (A1), U11.9 (Q3), U12.5 (A3)
SPI_CLK: J1.4, J5.5, J5.6, U1.3 (Q0), U4.13, U6.11 (SRCLK)
TX_COMPLETE: U1.11 (Q0), U4.3, U6.12 (RCLK)
~CS0: J1.5, J5.9, J5.10, U3.4 (O0)
~CS1: J1.6, U3.5 (O1)
~CS2: J1.7, U3.6 (O2)
~CS3: J1.8, U3.7 (O3)
~CS: J2.16, U4.11
~CS_{QUAL}: U2.8, U3.15 (E)
~CTRL_RD: U3.9 (O3), U12.19 (CE)
~CTRL_WR: U3.10 (O2), U11.11 (Cp)
~DATA_RD: U3.11 (O1), U5.2, U6.13 (~OE)
~DATA_WR: U3.12 (O0), U5.1, U7.1 (~PL), U9.10 (~S)
~IRQ: J2.11, U2.11
~ITC_RES: U5.6, U9.1 (~R)
~RES: J2.10, U2.1, U5.5, U5.10, U11.1 (~Mr)
~SPI_CLK: U4.12, U7.2 (CP)
~TX_COMPLETE_RES: U5.8, U9.4 (~S), U9.13 (~R)

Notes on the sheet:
Clock Select
ITC
Control Register
DEN
Other Signal Generation
Finite State Machine
IEN
SEL0
Power and Decoupling
DIV1
Device Select
Options: 1. CPU Clk 2. / 4 3. / 8 4. / 16 SPI clk is further divided by 2 so you get: 1. / 2 2. / 8 3. / 16 4. / 32 Slowest given cpu clock of 8mhz is 250khz and fastest is 4mhz
Register Decoding
Data (Shift) Registers
SEL1
16 States 0: Idle 1-15: shifting 16: Transfer Complete
DIV0
BUSY

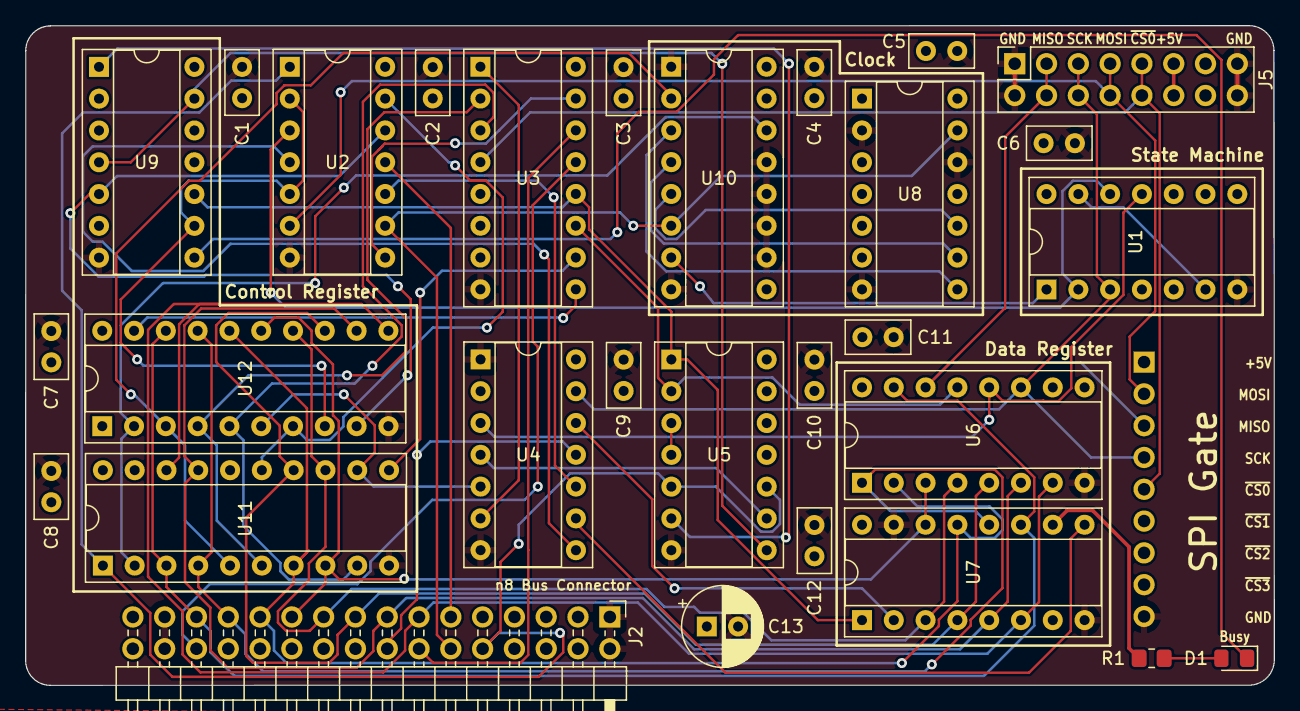
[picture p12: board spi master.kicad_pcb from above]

Board: 4 copper layers, 99.7 x 52.7 mm, 30 parts (1 on the bottom side), 54 nets.

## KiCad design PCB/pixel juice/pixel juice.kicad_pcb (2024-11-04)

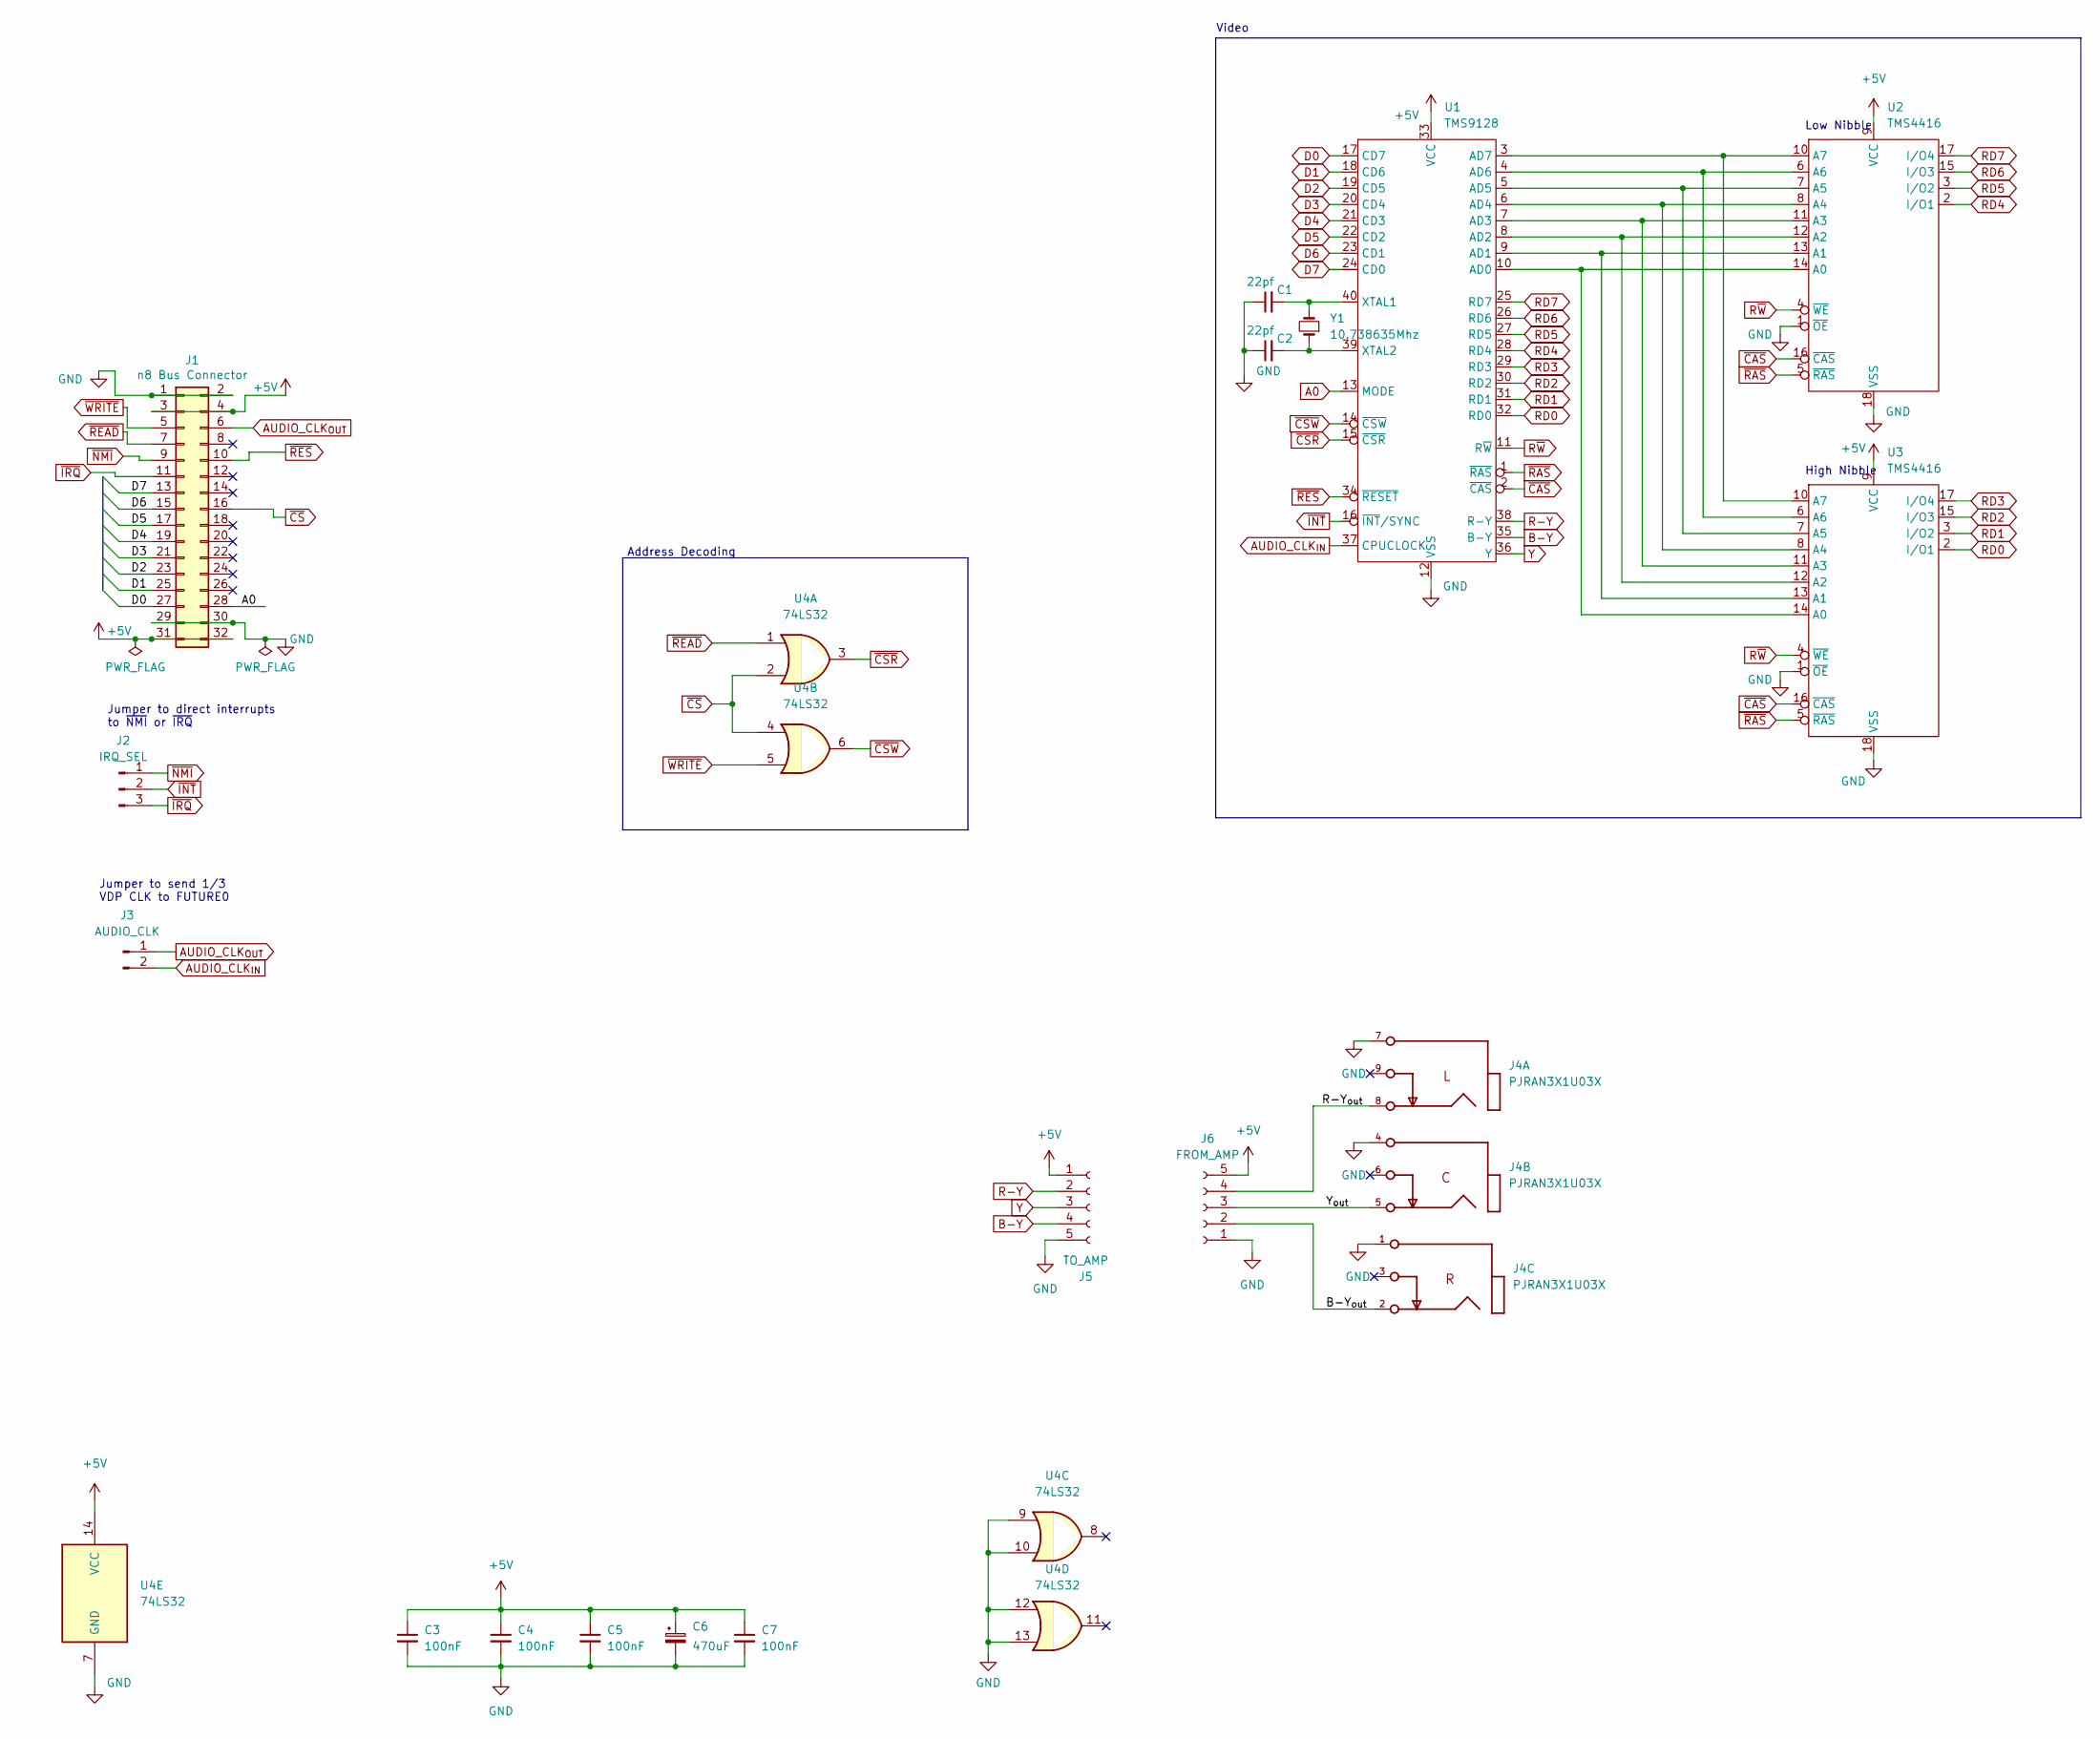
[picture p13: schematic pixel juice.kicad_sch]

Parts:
C1, C2: 22pf; C_Disc_D5.0mm_W2.5mm_P2.50mm
C3, C4, C5, C7: 100nF; C_0805_2012Metric_Pad1.18x1.45mm_HandSolder
C6: 470uF; CP_Radial_D8.0mm_P3.80mm
J1: n8 Bus Connector; PinHeader_2x16_P2.54mm_Horizontal
J2: IRQ_SEL; PinHeader_1x03_P2.54mm_Vertical
J3: AUDIO_CLK; PinHeader_1x02_P2.54mm_Vertical
J4: PJRAN3X1U03X; PJRAN3X1U01X
J5: TO_AMP; PinSocket_1x05_P2.54mm_Vertical
J6: FROM_AMP; PinSocket_1x05_P2.54mm_Vertical
U1: TMS9128; DIP-40_W15.24mm_Socket
U2, U3: TMS4416; DIP-18_W7.62mm_Socket
U4: 74LS32; DIP-14_W7.62mm_Socket
Y1: 10.738635Mhz; Crystal_HC49-U_Horizontal

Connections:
+5V: C3.1, C4.1, C5.1, C6.1, C7.1, J1.3, J1.4, J1.31, J1.32, J5.1, J6.5, U1.33 (VCC), U2.9 (VCC), U3.9 (VCC), U4.14 (VCC)
/B-Y_{out}: J4.2, J6.2
/R-Y_{out}: J4.8, J6.4
/Y_{out}: J4.5, J6.3
A0: J1.28, U1.13 (MODE)
AUDIO_CLK_{IN}: J3.2, U1.37 (CPUCLOCK)
AUDIO_CLK_{OUT}: J1.6, J3.1
B-Y: J5.4, U1.35 (B-Y)
D0: J1.27, U1.17 (CD7)
D1: J1.25, U1.18 (CD6)
D2: J1.23, U1.19 (CD5)
D3: J1.21, U1.20 (CD4)
D4: J1.19, U1.21 (CD3)
D5: J1.17, U1.22 (CD2)
D6: J1.15, U1.23 (CD1)
D7: J1.13, U1.24 (CD0)
GND: C1.1, C2.1, C3.2, C4.2, C5.2, C6.2, C7.2, J1.1, J1.2, J1.29, J1.30, J4.1, J4.4, J4.7, J5.5, J6.1, U1.12 (VSS), U2.1 (~OE), U2.18 (VSS), U3.1 (~OE), U3.18 (VSS), U4.7 (GND), U4.9, U4.10, U4.12, U4.13
unnamed: C1.2, U1.40 (XTAL1), Y1.2
unnamed: C2.2, U1.39 (XTAL2), Y1.1
unnamed: U1.3 (AD7), U2.10 (A7), U3.10 (A7)
unnamed: U1.4 (AD6), U2.6 (A6), U3.6 (A6)
unnamed: U1.5 (AD5), U2.7 (A5), U3.7 (A5)
unnamed: U1.6 (AD4), U2.8 (A4), U3.8 (A4)
unnamed: U1.7 (AD3), U2.11 (A3), U3.11 (A3)
unnamed: U1.8 (AD2), U2.12 (A2), U3.12 (A2)
unnamed: U1.9 (AD1), U2.13 (A1), U3.13 (A1)
unnamed: U1.10 (AD0), U2.14 (A0), U3.14 (A0)
R-Y: J5.2, U1.38 (R-Y)
RD0: U1.32 (RD0), U3.2 (I/O1)
RD1: U1.31 (RD1), U3.3 (I/O2)
RD2: U1.30 (RD2), U3.15 (I/O3)
RD3: U1.29 (RD3), U3.17 (I/O4)
RD4: U1.28 (RD4), U2.2 (I/O1)
RD5: U1.27 (RD5), U2.3 (I/O2)
RD6: U1.26 (RD6), U2.15 (I/O3)
RD7: U1.25 (RD7), U2.17 (I/O4)
R~W: U1.11 (R~W), U2.4 (~WE), U3.4 (~WE)
Y: J5.3, U1.36 (Y)
~CAS: U1.2 (~CAS), U2.16 (~CAS), U3.16 (~CAS)
~CSR: U1.15 (~CSR), U4.3
~CSW: U1.14 (~CSW), U4.6
~CS: J1.16, U4.2, U4.4
~INT: J2.2, U1.16 (~INT/SYNC)
~IRQ: J1.11, J2.3
~NMI: J1.9, J2.1
~RAS: U1.1 (~RAS), U2.5 (~RAS), U3.5 (~RAS)
~READ: J1.7, U4.1
~RES: J1.10, U1.34 (~RESET)
~WRITE: J1.5, U4.5

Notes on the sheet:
High Nibble
Low Nibble
Video
Address Decoding
Jumper to send 1/3 VDP CLK to FUTURE0
Jumper to direct interrupts to ~{NMI} or ~{IRQ}

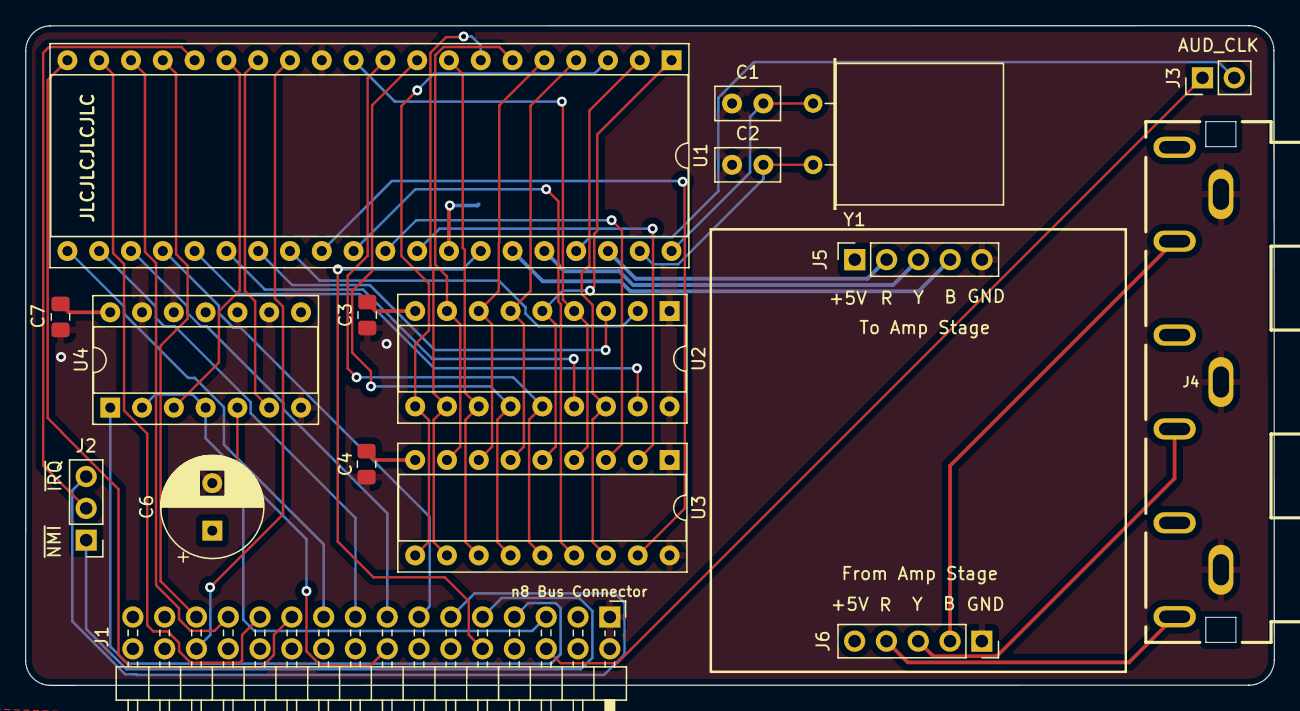
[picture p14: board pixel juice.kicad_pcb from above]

Board: 4 copper layers, 99.7 x 52.7 mm, 18 parts (1 on the bottom side), 49 nets.

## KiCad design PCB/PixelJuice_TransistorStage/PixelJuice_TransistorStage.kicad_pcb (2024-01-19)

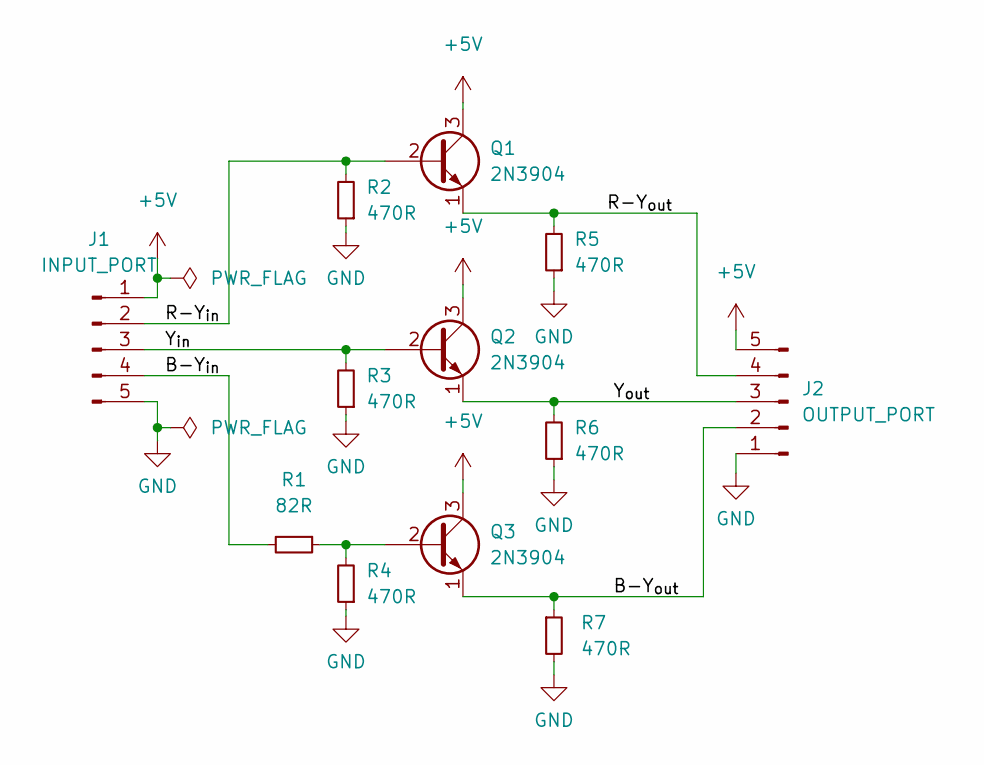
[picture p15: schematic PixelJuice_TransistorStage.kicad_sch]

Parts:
J1: INPUT_PORT; PinHeader_1x05_P2.54mm_Vertical
J2: OUTPUT_PORT; PinHeader_1x05_P2.54mm_Vertical
Q1, Q2, Q3: 2N3904; TO-92_Inline
R1: 82R; R_Axial_DIN0207_L6.3mm_D2.5mm_P7.62mm_Horizontal
R2, R3, R4, R5, R6, R7: 470R; R_Axial_DIN0207_L6.3mm_D2.5mm_P7.62mm_Horizontal

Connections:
+5V: J1.1, J2.5, Q1.3 (C), Q2.3 (C), Q3.3 (C)
/B-Y_{in}: J1.4, R1.2
/B-Y_{out}: J2.2, Q3.1 (E), R7.1
/R-Y_{in}: J1.2, Q1.2 (B), R2.2
/R-Y_{out}: J2.4, Q1.1 (E), R5.2
/Y_{in}: J1.3, Q2.2 (B), R3.2
/Y_{out}: J2.3, Q2.1 (E), R6.2
GND: J1.5, J2.1, R2.1, R3.1, R4.1, R5.1, R6.1, R7.2
unnamed: Q3.2 (B), R1.1, R4.2

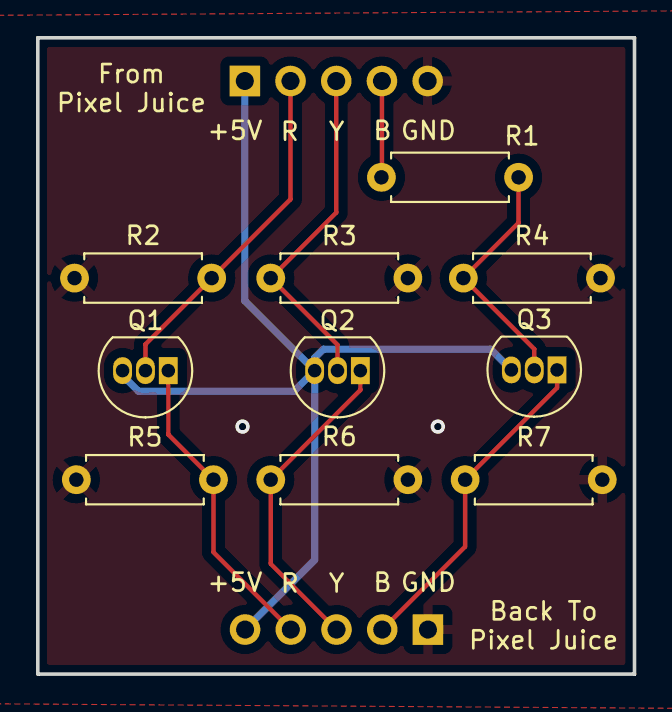
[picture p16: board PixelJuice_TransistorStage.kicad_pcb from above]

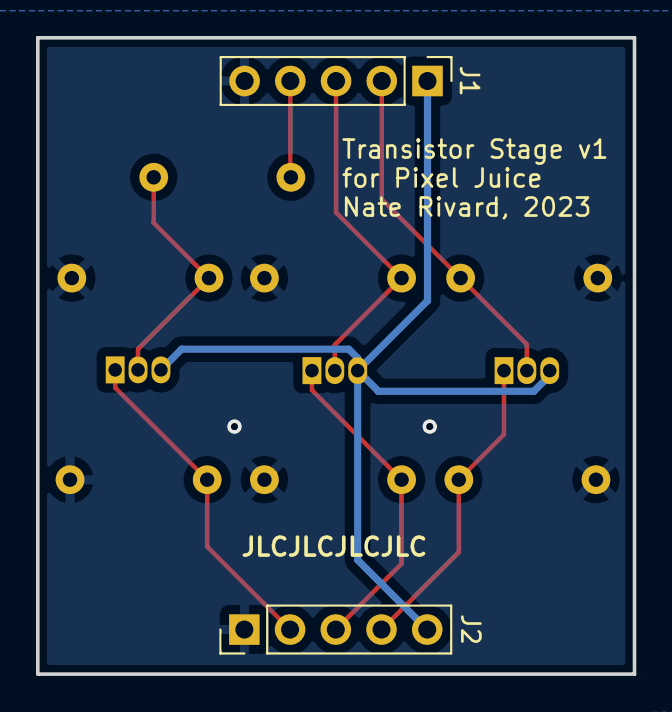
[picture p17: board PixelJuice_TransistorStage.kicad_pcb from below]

Board: 2 copper layers, 33.2 x 35.3 mm, 12 parts (2 on the bottom side), 9 nets.

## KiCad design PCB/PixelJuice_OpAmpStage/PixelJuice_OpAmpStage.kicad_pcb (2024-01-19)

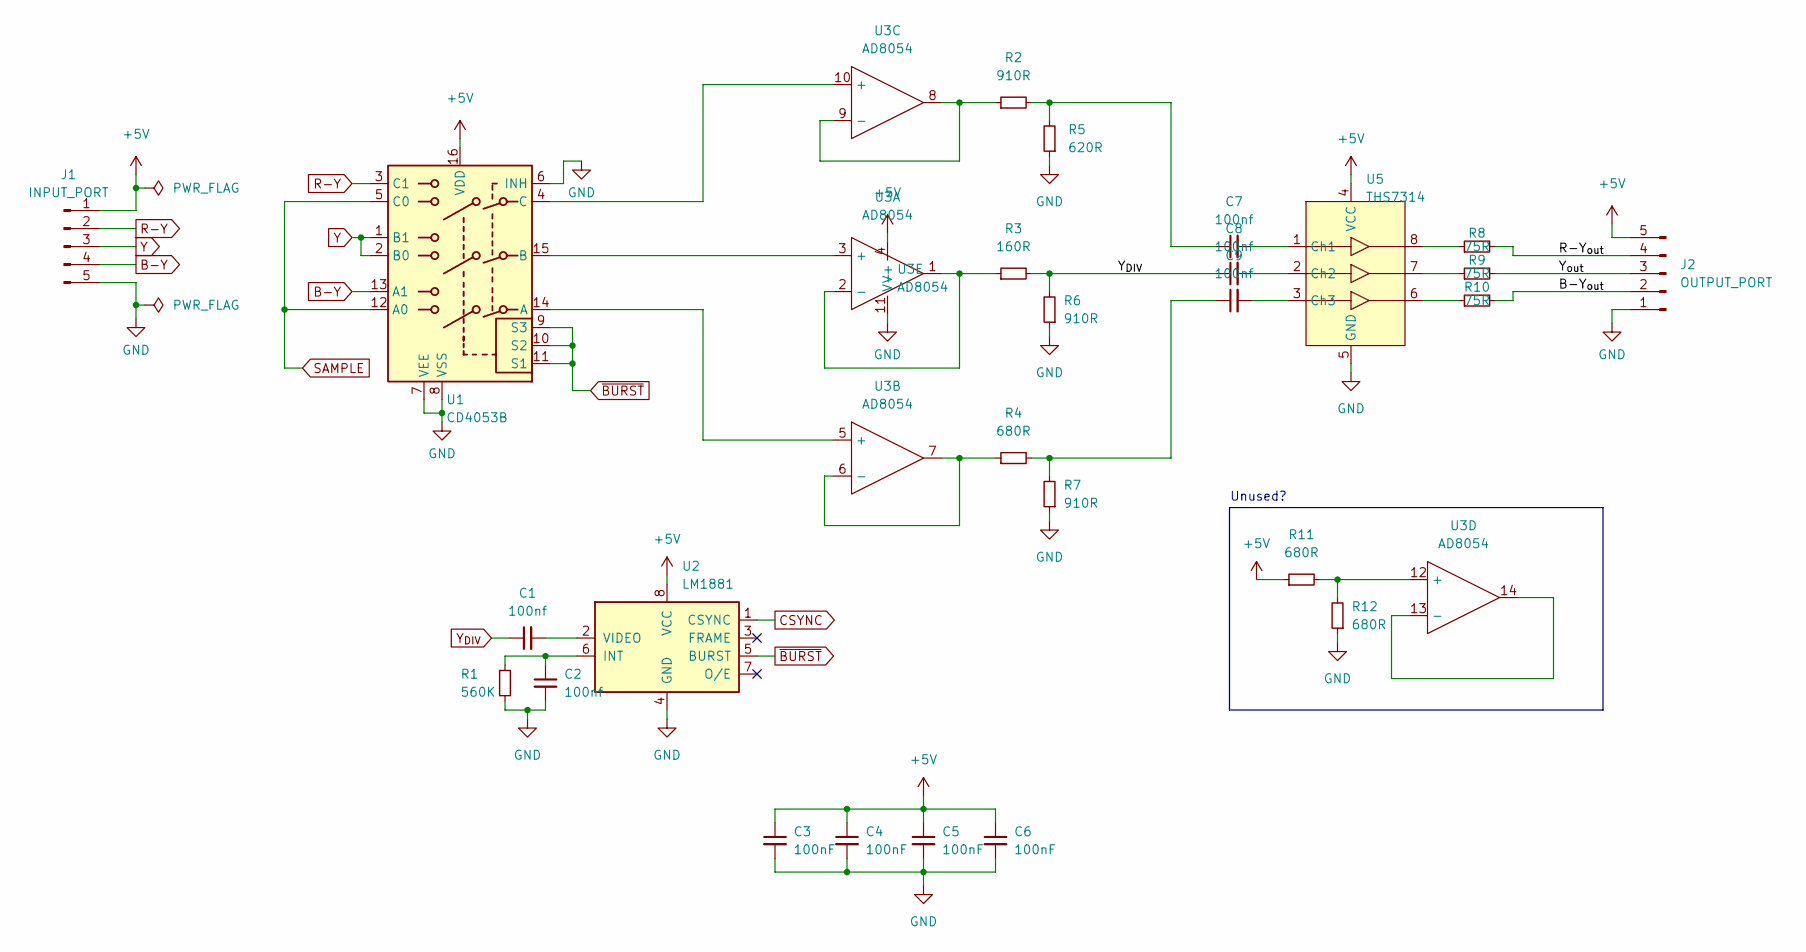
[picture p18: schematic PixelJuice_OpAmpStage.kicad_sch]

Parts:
C1, C2, C7, C8, C9: 100nf; C_0805_2012Metric_Pad1.18x1.45mm_HandSolder
C3, C4, C5, C6: 100nF; C_0805_2012Metric_Pad1.18x1.45mm_HandSolder
J1: INPUT_PORT; PinHeader_1x05_P2.54mm_Vertical
J2: OUTPUT_PORT; PinHeader_1x05_P2.54mm_Vertical
R1: 560K; R_0805_2012Metric_Pad1.20x1.40mm_HandSolder
R2, R6, R7: 910R; R_0805_2012Metric_Pad1.20x1.40mm_HandSolder
R3: 160R; R_0805_2012Metric_Pad1.20x1.40mm_HandSolder
R4, R11, R12: 680R; R_0805_2012Metric_Pad1.20x1.40mm_HandSolder
R5: 620R; R_0805_2012Metric_Pad1.20x1.40mm_HandSolder
R8, R9, R10: 75R; R_0805_2012Metric_Pad1.20x1.40mm_HandSolder
U1: CD4053B; DIP-16_W7.62mm_Socket
U2: LM1881; DIP-8_W7.62mm
U3: AD8054; SOIC-14_3.9x8.7mm_P1.27mm
U5: THS7314; SOIC-8_3.9x4.9mm_P1.27mm

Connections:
+5V: C3.1, C4.1, C5.1, C6.1, J1.1, J2.5, R11.1, U1.16 (VDD), U2.8 (VCC), U3.4 (V+), U5.4 (VCC)
/B-Y_{out}: J2.2, R10.2
/R-Y_{out}: J2.4, R8.2
/Y_{out}: J2.3, R9.2
B-Y: J1.4, U1.13 (A1)
CSYNC: U2.1 (CSYNC)
GND: C2.2, C3.2, C4.2, C5.2, C6.2, J1.5, J2.1, R1.2, R5.1, R6.1, R7.1, R12.1, U1.6 (INH), U1.7 (VEE), U1.8 (VSS), U2.4 (GND), U3.11 (V-), U5.5 (GND)
unnamed: C1.2, U2.2 (VIDEO)
unnamed: C2.1, R1.1, U2.6 (INT)
unnamed: C7.1, R2.2, R5.2
unnamed: C7.2, U5.1 (Ch1)
unnamed: C8.2, U5.2 (Ch2)
unnamed: C9.1, R4.2, R7.2
unnamed: C9.2, U5.3 (Ch3)
unnamed: R2.1, U3.8, U3.9 (-)
unnamed: R3.1, U3.1, U3.2 (-)
unnamed: R4.1, U3.6 (-), U3.7
unnamed: R8.1, U5.8
unnamed: R9.1, U5.7
unnamed: R10.1, U5.6
unnamed: R11.2, R12.2, U3.12 (+)
unnamed: U1.4 (C), U3.10 (+)
unnamed: U1.14 (A), U3.5 (+)
unnamed: U1.15 (B), U3.3 (+)
unnamed: U3.13 (-), U3.14
R-Y: J1.2, U1.3 (C1)
SAMPLE: U1.5 (C0), U1.12 (A0)
Y: J1.3, U1.1 (B1), U1.2 (B0)
Y_{DIV}: C1.1, C8.1, R3.2, R6.2
~BURST: U1.9 (S3), U1.10 (S2), U1.11 (S1), U2.5 (BURST)

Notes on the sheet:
Unused?

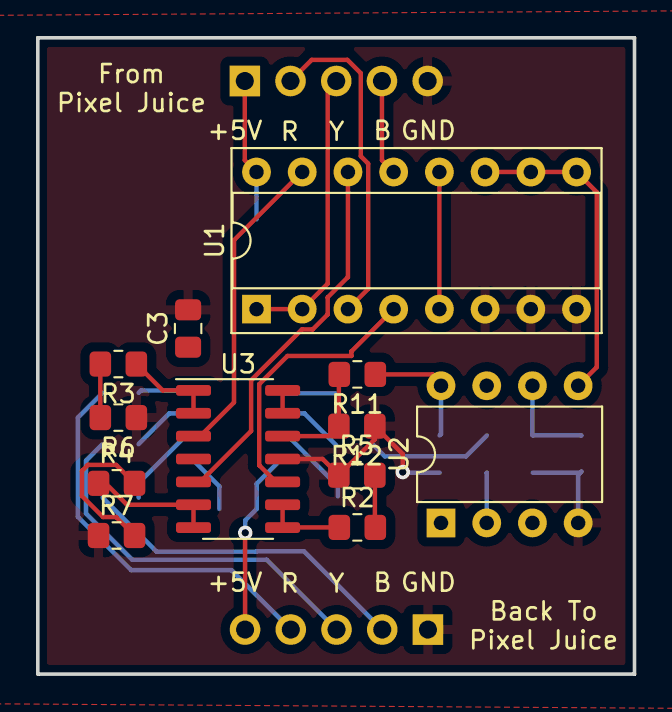
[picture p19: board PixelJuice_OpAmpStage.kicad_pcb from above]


Board: 2 copper layers, 33.2 x 35.4 mm, 27 parts (15 on the bottom side), 29 nets.

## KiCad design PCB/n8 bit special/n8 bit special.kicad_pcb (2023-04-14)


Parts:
C1, C3, C4, C5, C6, C7, C8, C11, C12, C13, C14, C15, C16: 100nf; C_Disc_D5.0mm_W2.5mm_P2.50mm
C2: 470uF; CP_Radial_D8.0mm_P3.80mm
C9, C10, C17, C18: 100nF; C_Disc_D5.0mm_W2.5mm_P2.50mm
D1, D2, D3: LED_ALT; LED_D3.0mm
J1: USB_B_Micro; USB_Micro-B_Wuerth_629105150521
J2: PORT0; PinSocket_2x16_P2.54mm_Vertical
J3: PORT1; PinSocket_2x16_P2.54mm_Vertical
J4: PORT2; PinSocket_2x16_P2.54mm_Vertical
J6: Conn_02x08_Odd_Even; PinHeader_2x06_P2.54mm_Vertical
Q1: 2N3904; TO-92
R1, R3, R5: 220; R_Axial_DIN0207_L6.3mm_D2.5mm_P7.62mm_Horizontal
R2: 3K3; R_Axial_DIN0207_L6.3mm_D2.5mm_P7.62mm_Horizontal
R4: 10K; R_Axial_DIN0207_L6.3mm_D2.5mm_P7.62mm_Horizontal
RN1: 3K3; R_Array_SIP9
SW1: SW_Push_Dual; SW_PUSH_6mm
U1: W65C02SxP; PLCC-44_THT-Socket
U2, U3: CY62256-70PC; DIP-28_W15.24mm_Socket
U4: 28C256; DIP-28_W15.24mm_Socket
U5: SC28L92_PLC44; PLCC-44_THT-Socket
U6: 22V10C; DIP-24_W7.62mm_Socket
U7: DS1813; TO-92; MANUFACTURER_PART_NUMBER ds181315+
U8: CH340C; SOIC-16_3.9x9.9mm_P1.27mm
U9: 74LS21; DIP-14_W7.62mm_Socket
U10: 74HC00; DIP-14_W7.62mm_Socket
X1: 3.6864Mhz; Oscillator_DIP-8

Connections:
+5V: C1.2, C2.1, C3.2, C4.1, C5.2, C6.1, C7.2, C8.1, C9.1, C11.1, C12.1, C13.1, C14.1, C15.2, C16.2, C17.1, C18.1, D2.2 (A), D3.2 (A), J1.1 (VBUS), J2.1, J2.2, J2.29, J2.30, J3.1, J3.2, J3.29, J3.30, J4.1, J4.2, J4.29, J4.30, Q1.3 (C), R2.2, RN1.1 (common), U1.9 (VDD), U1.37 (VDD), U1.42 (~SO), U2.28 (VCC), U3.28 (VCC), U4.27 (~WE), U4.28 (VCC), U5.12 (I/M), U5.44 (VCC), U6.24 (VCC), U7.2 (VCC), U8.16 (VCC), U9.13, U9.14 (VCC), U10.14 (VCC), X1.8 (Vcc)
/A0: J2.5, J3.5, J4.5, U1.10 (A0), U2.10 (A0), U3.10 (A0), U4.10 (A0), U5.2 (A0)
/A1: J2.7, J3.7, J4.7, U1.11 (A1), U2.9 (A1), U3.9 (A1), U4.9 (A1), U5.4 (A1)
/A2: J2.9, J3.9, J4.9, U1.13 (A2), U2.8 (A2), U3.8 (A2), U4.8 (A2), U5.6 (A2)
/A3: J2.11, J3.11, J4.11, U1.14 (A3), U2.7 (A3), U3.7 (A3), U4.7 (A3), U5.7 (A3)
/A4: J2.13, J3.13, J4.13, U1.15 (A4), U2.6 (A4), U3.6 (A4), U4.6 (A4)
/A5: J2.15, J3.15, J4.15, U1.16 (A5), U2.5 (A5), U3.5 (A5), U4.5 (A5)
/A6: U1.17 (A6), U2.4 (A6), U3.4 (A6), U4.4 (A6), U6.2 (IN2)
/A7: U1.18 (A7), U2.3 (A7), U3.3 (A7), U4.3 (A7), U6.3 (IN3)
/A8: U1.19 (A8), U2.25 (A8), U3.25 (A8), U4.25 (A8), U6.4 (IN4/PD)
/A9: U1.20 (A9), U2.24 (A9), U3.24 (A9), U4.24 (A9), U6.5 (IN5)
/A10: U1.21 (A10), U2.21 (A10), U3.21 (A10), U4.21 (A10), U6.6 (IN6)
/A11: U1.22 (A11), U2.23 (A11), U3.23 (A11), U4.23 (A11), U6.7 (IN7)
/A12: U1.25 (A12), U2.2 (A12), U3.2 (A12), U4.2 (A12), U6.8 (IN8)
/A13: U1.26 (A13), U2.26 (A13), U3.26 (A13), U4.26 (A13), U6.9 (IN9)
/A14: U1.27 (A14), U2.1 (A14), U3.1 (A14), U4.1 (A14), U6.10 (IN10)
/A15: U1.28 (A15), U6.11 (IN11)
/D0: J2.6, J3.6, J4.6, U1.36 (D0), U2.11 (Q0), U3.11 (Q0), U4.11 (D0), U5.28 (D0)
/D1: J2.8, J3.8, J4.8, U1.35 (D1), U2.12 (Q1), U3.12 (Q1), U4.12 (D1), U5.18 (D1)
/D2: J2.10, J3.10, J4.10, U1.34 (D2), U2.13 (Q2), U3.13 (Q2), U4.13 (D2), U5.27 (D2)
/D3: J2.12, J3.12, J4.12, U1.33 (D3), U2.15 (Q3), U3.15 (Q3), U4.15 (D3), U5.19 (D3)
/D4: J2.14, J3.14, J4.14, U1.32 (D4), U2.16 (Q4), U3.16 (Q4), U4.16 (D4), U5.26 (D4)
/D5: J2.16, J3.16, J4.16, U1.31 (D5), U2.17 (Q5), U3.17 (Q5), U4.17 (D5), U5.20 (D5)
/D6: J2.18, J3.18, J4.18, U1.30 (D6), U2.18 (Q6), U3.18 (Q6), U4.18 (D6), U5.25 (D6)
/D7: J2.20, J3.20, J4.20, U1.29 (D7), U2.19 (Q7), U3.19 (Q7), U4.19 (D7), U5.21 (D7)
BE_PULLUP: RN1.9 (R8), U1.40 (BE)
CLK: J2.21, J3.21, J4.21, U1.41 (ϕ0), U5.36 (X1/CLK), U6.1 (CLK/IN1), U10.2, U10.4, X1.5 (OUT)
FUTURE0: J2.25, J3.25, J4.25, U6.15 (IO14)
FUTURE1: J2.27, J3.27, J4.27, U6.14 (IO13)
GND: C1.1, C2.2, C3.1, C4.2, C5.1, C6.2, C7.1, C8.2, C9.2, C10.2, C11.2, C12.2, C13.2, C14.2, C15.1, C16.1, C17.2, C18.2, J1.5 (GND), J2.3, J2.4, J2.31, J2.32, J3.3, J3.4, J3.31, J3.32, J4.3, J4.4, J4.31, J4.32, R1.2, SW1.2 (D), U1.1 (VSS), U1.23 (VSS), U1.24 (VSS), U2.14 (GND), U3.14 (GND), U4.14 (GND), U5.22 (GND), U6.12 (GND), U7.3 (GND), U8.1 (GND), U9.7 (GND), U10.7 (GND), X1.4 (GND)
unnamed: C10.1, U8.4 (V3)
unnamed: D1.1 (K), R1.1
unnamed: D1.2 (A), Q1.1 (E)
unnamed: D2.1 (K), R3.1
unnamed: D3.1 (K), R5.1
unnamed: J6.2, RN1.3 (R2)
unnamed: J6.4, RN1.4 (R3)
unnamed: J6.6, RN1.5 (R4)
unnamed: J6.8, RN1.6 (R5)
unnamed: J6.10, RN1.7 (R6)
unnamed: J6.12, RN1.8 (R7)
unnamed: Q1.2 (B), R4.1
unnamed: U10.1, U10.8
PORT0_IRQ_PULLUP: J2.22, J6.1, U9.1
PORT0_NMI_PULLUP: J2.24, J6.3, U9.9
PORT1_IRQ_PULLUP: J3.22, J6.5, U9.2
PORT1_NMI_PULLUP: J3.24, J6.7, U9.10
PORT2_IRQ_PULLUP: J4.22, J6.9, U9.4
PORT2_NMI_PULLUP: J4.24, J6.11, U9.12
RDY_PULLUP: RN1.2 (R1), U1.3 (RDY)
RxD: R3.2, U5.35 (RxDA), U8.2 (TXD)
R~W: J2.19, J3.19, J4.19, U1.38 (R/~W), U6.13 (IN12), U10.5, U10.9, U10.10
TxD: R5.2, U5.33 (TxDA), U8.3 (RXD)
UART_RES: U5.38 (RESET), U10.11
USB_D+: J1.3 (D+), U8.5 (UD+)
USB_D-: J1.2 (D-), U8.6 (UD-)
~CTS: U5.8 (IP0), U8.14 (~RTS)
~IRQ: U1.5 (~IRQ), U9.6
~NMI: U1.7 (~NMI), U9.8
~PORT0_CS: J2.17, U6.20 (IO19)
~PORT1_CS: J3.17, U6.19 (IO18)
~PORT2_CS: J4.17, U6.18 (IO17)
~RAM1_CS: U2.20 (~CS), U6.22 (IO21)
~RAM2_CS: U3.20 (~CS), U6.21 (IO20)
~READ: J2.26, J3.26, J4.26, U2.22 (~OE), U3.22 (~OE), U4.22 (~OE), U5.10 (~RDN), U10.6
~RES: J2.23, J3.23, J4.23, R4.2, SW1.1 (C), U1.44 (~RES), U7.1 (~RES), U10.12, U10.13
~ROM_CS: U4.20 (~CS), U6.23 (IO22)
~RTS: U5.32 (OP0), U8.9 (~CTS)
~UART_CS: U5.39 (~CEN), U6.17 (IO16)
~UART_IRQ: R2.1, U5.24 (~INTRN), U9.5
~WRITE: J2.28, J3.28, J4.28, U2.27 (~WE), U3.27 (~WE), U5.9 (~WRN), U10.3

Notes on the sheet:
Expansion Ports
UART and USB
Memory
Configured for Intel Bus Mode
CPU
Power
Reset
Qualified Signals
Glue Logic
System Clock
Device Interrupts


Board: 4 copper layers, 99.9 x 100.0 mm, 47 parts (0 on the bottom side), 71 nets.

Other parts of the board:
G1: LOGO; Shaka
G2: LOGO; MadeInAMS

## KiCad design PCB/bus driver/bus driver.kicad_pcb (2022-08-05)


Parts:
BAR1: HDSP-4850_2; HDSP-4850
C1, C2: 100nf; C_Disc_D5.0mm_W2.5mm_P2.50mm
J1: Conn_01x10_Female; PinSocket_1x10_P2.54mm_Vertical
R1: 3K3; R_Axial_DIN0207_L6.3mm_D2.5mm_P7.62mm_Horizontal
RN1: 3K3; R_Array_SIP9
RN2: 330R; R_Array_SIP9
SW1: SW_DIP_x08; SW_DIP_SPSTx08_Slide_9.78x22.5mm_W7.62mm_P2.54mm
SW2: SW_SPDT; PinHeader_1x03_P2.54mm_Vertical
U1, U2: 74HC245; DIP-20_W7.62mm

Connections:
+5V: C1.1, C2.1, J1.1, R1.2, SW1.1, SW1.2, SW1.3, SW1.4, SW1.5, SW1.6, SW1.7, SW1.8, U1.1 (A->B), U1.20 (VCC), U2.1 (A->B), U2.20 (VCC)
/D0: J1.9, U1.11 (B7), U2.9 (A7)
/D1: J1.8, U1.12 (B6), U2.8 (A6)
/D2: J1.7, U1.13 (B5), U2.7 (A5)
/D3: J1.6, U1.14 (B4), U2.6 (A4)
/D4: J1.5, U1.15 (B3), U2.5 (A3)
/D5: J1.4, U1.16 (B2), U2.4 (A2)
/D6: J1.3, U1.17 (B1), U2.3 (A1)
/D7: J1.2, U1.18 (B0), U2.2 (A0)
GND: C1.2, C2.2, J1.10, RN1.1 (common), RN2.1 (common), SW2.1 (A), U1.10 (GND), U2.10 (GND), U2.19 (CE)
unnamed: BAR1.2 (A), U2.18 (B0)
unnamed: BAR1.3 (A), U2.17 (B1)
unnamed: BAR1.4 (A), U2.16 (B2)
unnamed: BAR1.5 (A), U2.15 (B3)
unnamed: BAR1.6 (A), U2.14 (B4)
unnamed: BAR1.7 (A), U2.13 (B5)
unnamed: BAR1.8 (A), U2.12 (B6)
unnamed: BAR1.9 (A), U2.11 (B7)
unnamed: BAR1.12 (K), RN2.9 (R8)
unnamed: BAR1.13 (K), RN2.8 (R7)
unnamed: BAR1.14 (K), RN2.7 (R6)
unnamed: BAR1.15 (K), RN2.6 (R5)
unnamed: BAR1.16 (K), RN2.5 (R4)
unnamed: BAR1.17 (K), RN2.4 (R3)
unnamed: BAR1.18 (K), RN2.3 (R2)
unnamed: BAR1.19 (K), RN2.2 (R1)
unnamed: RN1.2 (R1), SW1.9, U1.9 (A7)
unnamed: RN1.3 (R2), SW1.10, U1.8 (A6)
unnamed: RN1.4 (R3), SW1.11, U1.7 (A5)
unnamed: RN1.5 (R4), SW1.12, U1.6 (A4)
unnamed: RN1.6 (R5), SW1.13, U1.5 (A3)
unnamed: RN1.7 (R6), SW1.14, U1.4 (A2)
unnamed: RN1.8 (R7), SW1.15, U1.3 (A1)
unnamed: RN1.9 (R8), SW1.16, U1.2 (A0)
~OE: R1.1, SW2.2 (B), U1.19 (CE)


Board: 2 copper layers, 48.3 x 65.5 mm, 11 parts (0 on the bottom side), 35 nets.

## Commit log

2021-09-01 V1 of n8 Bit Special
    This is the V1 hardware schematic + PCBs that were actually printed. This includes a *hardware defect* where voltage was not stable bc the LED caused a voltage drop. This is fixed in V2 via an additional buffering transitor (hopefully) that could get backported to make V1 functional. The ports are also too close together to really be able to use all 4 ports unless no sockets are used and the chips on the board are very thin. This is also addressed in V2. But I think it important to at least keep the original version.
    Lastly, the GAL logic here _does_ include a fix. Previously, both RAM_CS signals were _not qualified_ with phi2. This is bad! So this version includes a GA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
    [kids serial.kicad_pcb, kids serial.sch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]
2021-09-01 Updated README and bodge wire picture
2021-09-06 New placement and parts for v2
    [kids serial-B_Cu.gbr, kids serial-B_Mask.gbr, kids serial-B_Paste.gbr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]
2021-09-06 Used Freerouter to route 4 layer PCB
    Had to touch up inner well area on the UART as it was disconnected to the rest of the power plane.
    [n8 bit special.dsn, n8 bit special.kicad_pcb]
2021-09-07 Layout centered around USB D+/D- differential pair
    [n8 bit special-B_Cu.gbr, n8 bit special-B_Mask.gbr, n8 bit special-B_Paste.gbr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]
2021-09-07 v2 release candidate
    [n8 bit special-B_Cu.gbr, n8 bit special-B_Mask.gbr, n8 bit special-B_Paste.gbr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]
2021-11-30 Prep for n8 bus pinout changes
    [n8 bit special.kicad_pcb]
2021-11-30 n8 bus card template updated
    [n8 bus.kicad_pcb, n8 bus.sch]
2022-01-05 release candidate for v2
    [n8 bit special-B_Cu.gbr, n8 bit special-B_Mask.gbr, n8 bit special-B_Paste.gbr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]
2022-01-05 v2 of viaduct
    [viaduct-B_Cu.gbr, viaduct-B_Mask.gbr, viaduct-B_Paste.gbr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]
2022-04-22 v2 changes
    [bouncer.kicad_pcb, bouncer.sch, file61D5CA66.sch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]
2022-05-15 Converted USB chip to CH340C which is more available Converted USB chip to CH340C which is more available and easier to solder :)
    [n8 bit special.kicad_pcb, n8 bit special.kicad_sch]
2022-05-20 Fixed D+/D- miswiring
    [n8 bit special.kicad_pcb, n8 bit special.kicad_sch]
2022-08-05 Final changes for v2
    [bouncer.kicad_pcb, bouncer.kicad_sch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]
2023-02-26 Start of VDP based gfx card
    [PJRAN3X1U03X.step, example.kicad_pcb, example.kicad_sch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]
2023-02-28 horizontal layout for vram but i want to try vertical
    [pixel juice.kicad_pcb, pixel juice.kicad_sch]
2023-03-23 Video card + bus driver changes
    [n8 bit special.kicad_pcb, pixel juice.kicad_pcb, pixel juice.kicad_sch]
2023-03-29 going to make v1 of the video card modular
    [pixel juice.kicad_sch]
2023-03-29 Added amp stages
    [PixelJuice_OpAmpStage.kicad_pcb, PixelJuice_OpAmpStage.kicad_sch, PixelJuice_TransistorStage.kicad_pcb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]
2023-04-14 rc1 before library swap test
    [n8 bit special.kicad_pcb, pixel juice.dsn, pixel juice.kicad_pcb]
2024-01-19 added 2 new soundcard designs
    [PixelJuice_OpAmpStage.kicad_pcb, PixelJuice_OpAmpStage.kicad_sch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]
2024-10-16 Worked on Spi master a little bit
    [Yamahawk2.kicad_sch, spi master.kicad_sch]
2024-10-21 Working simulation...
    [spi master.kicad_pcb, spi master.kicad_sch]
2024-10-22 Moved sub-circuits to top level for better visualization Fixed a bug with ITC being set on /RES Tracked down that inconsistent MOSI output is due to '165 being LEVEL sensitive not EDGE sensitive (no 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
2024-10-24 circuit in Digital is working, tested in real world
    [spi master.kicad_sch]
2024-10-25 3 signals away from SPI Master PCB
    [spi master.kicad_pcb, spi master.kicad_sch]
2024-11-04 rc1 for SPI Gate (prev SPI master) rc1 for Bouncer
    [bouncer.kicad_pcb, bouncer.kicad_sch, pixel juice.kicad_pcb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]
2025-07-02 Added SpiMaster support
    [Yamahawk1.kicad_pcb, Yamahawk1.kicad_sch, Yamahawk2.kicad_sch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]
